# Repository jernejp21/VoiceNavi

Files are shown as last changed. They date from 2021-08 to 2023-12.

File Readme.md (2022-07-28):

# VoiceNavi
For operation manuals, refer to [VoiceNavi](http://www.voicenavi.co.jp/).

## Supported devices

- 5A2
- 5F2
- 5F1
- 5F9IH

To switch between different devices, use MS1<sup>*1</sup> and MS2<sup>*1</sup> solder pads.

MS2 | MS1 | Device
:---: | :---: | :---:
Open | Open | 5A2
Open | Closed | 5F2
Closed | Open | 5F1
Closed | Closed | 5F9IH

## Volume adjustment

If SW2 is put into position 1, 1st song in flash will continuously play and VR3 volume can be adjusted. If position 3 is selected, 1st song in flash will continuously play and VR4 volume can be adjusted. This can be used to adjust volume. Normal operation mode is position 2.

## How to use (on Windows)
To edit source code, use [E2 Studio](https://www.renesas.com/us/en/software-tool/e-studio). Version used for this project is 2021-04 (22.1.0).

**IMPORTANT! Use GCC compiler version 8.3.0.202004. Do not use 8.3.202102 or newer. Compiling doesn't work in 202102 version.**

For updating FW, use [Renesas Flash Programmer V3](https://www.renesas.com/us/en/software-tool/renesas-flash-programmer-programming-gui#download).
 - Power off the device and set **boot** jumper.
 - Move SBPOW1 switch from **Host** to **Slave**.
 - Plug in USB cable and connect to PC.
 - Power on the device. To check if the device is recognised by PC, go to Device Manager and look at Ports.

 device manager
 - In Renesas Flash Programmer, create new project.

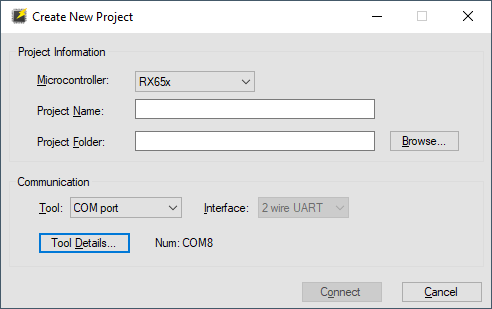
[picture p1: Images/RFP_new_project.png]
new project
 

 - Under *Tool* select *Com port*, under *Tool Details* select port which corresponds to RX USB Boot (Device Manager).
 - Click connect to check if you can connect to device. ID Code is all **F**s.
 - In operation tab, make sure you have **little endian** selected.
 - *Program File* is VoiceNavi.mot, located in VoiceNavi/HardwareDebug. If file or folder is missing, compile the project from E2 Studio or download the file from releases page.
 - Press *Start* button to begin download.
 - After download is completed, turn off power, unplug USB cable, move SBPOW1 back to **Host** and remove **boot** jumper.

## Copy from USB drive to internal flash procedure
To copy data from USB drive to flash, next procedure must be done. Before inserting USB drive, make sure it is formatted to FAT (FAT16, FAT32, exFAT) format and all needed wav files and only one wpj file is on USB drive. If this is not true, error will occur during copy procedure.

**Copy procedure:**
- Turn off power.
- Insert USB flash drive.
- Turn on power.
- During copy process, USB LED (green LED) will be turned on.
- If copying was successful, USB LED will blink in 0,5 s intervals. If errors occur, see error table.
- Turn off power.
- Remove USB flash drive.
- Turn on power.

## Errors table
If error occurs during any time when using VoiceNavi, check error table for details what the cause may be.

**LED colours and names:**
- ALARM - red (LED4)
- POWER - amber (LED1)
- BUSY - yellow (LED2)
- USB - green (LED3)

<table>
<thead>
  <tr>
    <th colspan="2">LED status</th>
    <th>Error type</th>
    <th>Possible cause</th>
  </tr>
</thead>
<tbody>
  <tr>
    <td>USB LED</td>
    <td>ALARM LED</td>
    <td></td>
    <td></td>
  </tr>
  <tr>
    <td>ON</td>
    <td>ON</td>
    <td>File system error</td>
    <td>Flash overflow.</td>
  </tr>
  <tr>
    <td>ON</td>
    <td>blinking (500 ms)</td>
    <td>Wave file error</td>
    <td>WAV file is missing.<br>WPJ file is missing.<br>WAV file is in stereo.<br>USB is formatted in wrong file system. Use FAT file system.</td>
  </tr>
  <tr>
    <td>OFF</td>
    <td>blinking (100 ms)</td>
    <td>Flash ECC error</td>
    <td>Bit error was detected and not corrected. Possibly deteriorated flash.</td>
  </tr>
  <tr>
    <td>OFF</td>
    <td>blinking (500 ms)</td>
    <td>Empty flash error</td>
    <td>No data in flash. Copy data from USB to internal flash.</td>
  </tr>
</tbody>
</table>

## Notes
Above described procedures apply to normal operation mode. If JP1 jumper is soldered, device is in debug mode. Device mode allows user to switch between board types using DIP switch.

*1 - In debug mode use DIP switch 7 and 8. MS1 is 7, MS2 is 8

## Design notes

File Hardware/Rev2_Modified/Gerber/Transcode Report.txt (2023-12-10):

   ---- Transcoding 'C:\Users\ALJAZT~1\AppData\Local\Temp\PCB2_importZIP\PCB2-NonPlated.TXT' ----   Mon May 02 20:12:58 2022

T9   --> T10
-----------------------------------------------------------------

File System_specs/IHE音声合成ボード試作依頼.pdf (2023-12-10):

有限会社 ハイツーシステム様
IHE 音声合成ボード開発依頼

2021 年 4 月 12 日

I.H.E. 井口
1 | 概要
| IHE では三共電子株式会社（以降三共とする）製音声再生ボード WAV-5F9-IH を販売しているが、
| 業務用 CF カード（低容量）の入手が困難になりつつある。
| そのため CF カードを廃止した、WAV-5F9-IH と搭載互換性がある、音声再生ボードの開発を行
| っていただく。
2 | 三共音声再生ボード WAV-5F9-IH 仕様

別紙 納入仕様書「WAVE ファイル再生ボード WAV5F9-IH00」（納入仕様書 WAV5F9-IH00.pdf） を参照して下さい。

3 | 開発音声再生ボード仕様
3.1 | WAV-5F9-IH と完全互換内容
- 基板外形寸法および基板取付穴
- 使用部品（相当品可）および部品配置

端子台：TB1／TB2
モードスイッチ：SW1

LED：LED1(POWER)／LED2(PLAY) ボリューム：VR3／VR4
- 機能および仕様
定格電圧、使用環境、再生方式、再生帯域、
モードスイッチ（プログラムローダ機能は別途相談）、
制御モードおよび CH 数、制御タイミング、
スピーカ出力、音量調整 VR3/VR4、

端子台 TB1/TB2 ピンアサイン、POWER-LED、PLAY-LED
3.2 三共音声再生ボードからの変更点
- 音声データおよび管理データが保存されている CF カードを廃止し、代わりにフラッシュメ モリ（128MB 以上）を搭載して下さい。
- マイコンおよびマイコン周辺回路の選定は一任します。
- オーディオ用 D/A コンバータの選定は一任します。
- D 級アンプと前段フィルタは、別紙 回路図「IH001V2 Rev:D1」（IHE001(D1).pdf） を参考にして下さい。
3.3 音声データと管理データ
- 三共製 VoiceNavi Editor で生成された音声ファイル（WAV ファイル）と管理ファイル（WPJ ファイル）を使用します。それらファイルを音声再生ボードに実装したフラッシュメモリに 転送し、制御入力に対した音声再生を行ないます。VoiceNavi Editor に相当するアプリケー

ションの開発は不要です。

- 転送方法は、別紙 三共 WAV-5M2F の方法（Lieflet_WAV5M2F.pdf）が望ましいですが、最 低機能として以下が実装できれば問題ありません。
- パソコン内にある三共製 VoiceNavi Editor で生成された音声ファイルと管理フ ァイルを、パソコン上で USB メモリあるいは SD カードにコピーする。
- USB メモリあるいは SD カードを音声再生ボードに装填し、音声再生ボードを 起動すると、音声ファイルと管理ファイルが音声再生ボード上のフラッシュメモ リにコピーされる。
- 音声再生ボードに USB メモリあるいは SD カードが装填されていなければ、フ ラッシュメモリから制御入力に対した音声再生を行う。
3.4 管理ファイル（WPJ ファイル）について
- 別紙に管理ファイル（4_01917A.wpj）テキスト形式を参照して下さい。必要な情報 はファイル内の#2 と#3 です。
- #2 では、ファイル番号に音声ファイル名を定義しています。音声ファイル名と拡張 子は、8 文字以下.3 文字以下です。

#2

0,NR053A.wav | ファイル番号 0 に NR053A.wav ファイルを紐づけ
1,NR047.wav | ファイル番号 1 に NR047.wav ファイルを紐づけ
2,056A.wav | ファイル番号 2 に 056A.wav ファイルを紐づけ
：

58,BB001.wav ファイル番号 58 に BB001.wav ファイルを紐づけ

- #3 では、制御入力 CH に対する、出力系統（1=VR3、2=VR4）、リピート回数、音声 ファイル組立を定義しています。
カンマ区切りで構成され、
1 番目は制御入力 CH（0=0x01、1=0x02…254=0xFF） 2 番目は出力系統（1=VR3 経由出力、2=VR4 経由出力） 3 番目はリピート回数
4 番目以降は音声ファイル組立（最大 8 ファイル）

#3

0,1,1,58 | 入力 0 は VR3 系統/リピート 1 回/ファイル番号 58 を再生
1,1,1,45 | 入力 1 は VR3 系統/リピート 1 回/ファイル番号 45 を再生
：
6,2,1,6 入力 6 は VR4 系統/リピート 1 回/ファイル番号 6 を再生
：

13,1,1,13,14 入力 13 は VR3 系統/リピート 1 回/ファイル番号 13,14 を組立再生

14,1,1,15,14 入力 14 は VR3 系統/リピート 1 回/ファイル番号 15,14 を組立再生

1 番目の後にカンマ区切りなしで * の場合は、その制御入力 CH は割り当てがないこ

とを意味し、再生は行われません。
8* | 入力 8 は音声再生なし

以上

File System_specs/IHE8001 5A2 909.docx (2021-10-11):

次期音声再生システムソフトウェア設計概要

2021/10/4 V0.3

有限会社ハイツーシステム

改訂履歴

Ver | 日付 | 概要 | 担当
０．２ | 2021/9/3 | 初期 | 池田
０．３ | 2021/10/4 | 一部変更 | 池田

# 1． 概要

次期音声再生システム（音声再生ボード）のソフトウェア概要について説明する。

本システムのおもな機能は以下の通りとする。

・再生用の音声データはPC上で作成された １つのコントロールファイル(.wpjファイル)＋WAVファイル(複数)のファイル群とする。

・これらのファイルを、USBフラッシュメモリにコピーし、USBフラッシュメモリから再生用ボードにコピーする。

・音声再生は、接点入力制御信号を起点として、格納された音声データを再生する。

・再生ボード上のPIOから入力さる接点制御信号はbit単位、またはバイナリコードとして解釈された番号を再生データのチャンネルデータとして、再生する。

・音声の再生モード機能は、旧WAV-5FIH、WAV-5F1、WAV-5F2ボードおよびWAV5A2の各機種と互換の再生モード機能を、合わせて搭載する。

# 2． 参照資料

参考資料として、以下のドキュメントを合わせて参照のこと。

ドキュメント名称 | 内容説明 | 発行者等メモ
IHE音声合成ボード試作依頼.pdf | 作成依頼仕様の概要 | IHE
納入仕様書WAV5F9-IH00.pdf | 前WAV-5F9IH再生ボード仕様書 | S社
65CIH02仕様書_IUK.PDF | 旧IH仕様音声再生ボード仕様
PS_WAV5F1_A130829.pdf | 製品仕様書 音声再生ボード WAV-5F1
PS_WAV5F2_C120416.pdf | 製品仕様書 音声再生ボード WAV-5F2
UM_WAV5F1_A130829.pdf | 取扱説明書4CH接点制御タイプ 音声再生ボード WAV-5F1
UM_WAV5F2_5F2R.pdf | 取扱説明書 音声再生ボード WAV-5F2
4_01917A.wpj | wpjサンプルファイル（テキスト）
音声再生ボード再生モード一覧.xlsx | 音声再生モード機能の資料 | Hi2

# 3． 設定機能について

本システムは、再生機能を実行する前に、ソフトウェアの基本機能を選択設定しておく必要がある。

それら選択項目について下記の基板レイアウト（暫定版）の位置をもとに説明をする。

図中の①~⑳番号で示す。

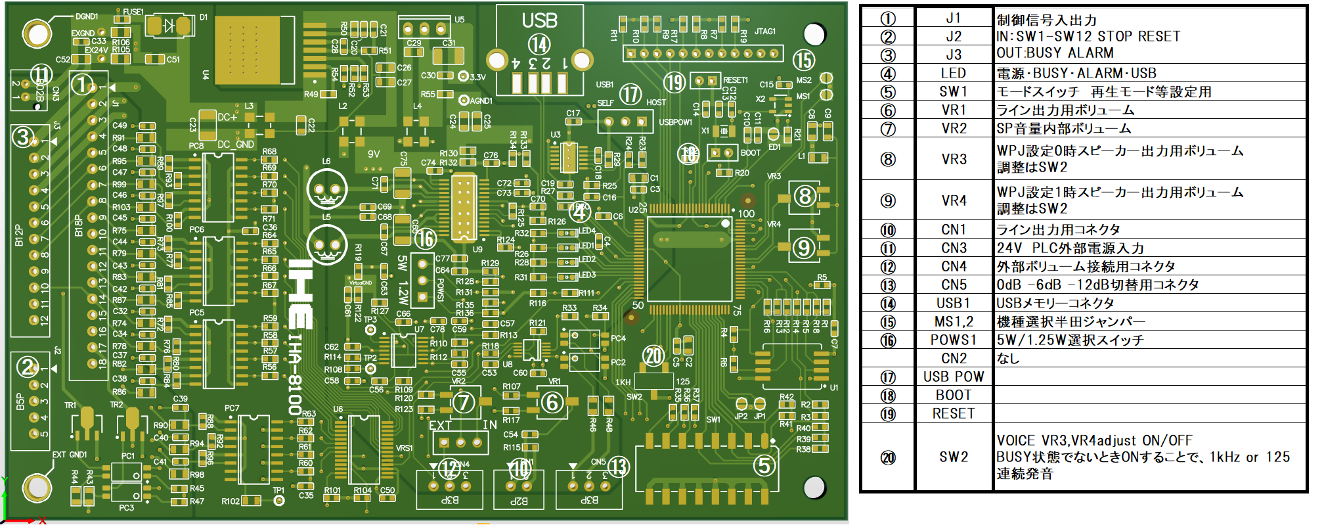
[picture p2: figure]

基板レイアウト暫定版

## 1） 機種の選択 ⑮

本システム（ボードおよびソフトウェア）は、4機種分の機能を内蔵している。これら4機種のどの機種で起動するかを、ボード上の半田ショート（PIO入力）により選択する。

選択する機種は次の 4機種である。

・WAV-5A2

・WAV-5F2

・WAV-5F1

・WAV-5F9

半田ショートパッドは2個あり、このパッドをショートすることにより選択する。

半田パッドNO | １ | ２
WAV-5A2 | オープン | オープン
WAV-5F2 | ショート | オープン
WAV-5F1 | オープン | ショート
WAV-5F9IH | ショート | ショート

## 2） 再生機能モード、その他の機能用 DIP-SW ⑤

再生モードなどソフトウェア機能の選択するために、DIP-SWが用意される。DIP-SWは８点のSWで、以下のように各機能を設定する。

DIP-SW機能設定

１ | ２ | ３ | 4 | 5 | ６ | ７ | ８
再生モードの設定 | | | インターバルタイマ設定 | | 未使用（予備）

a) 音声再生モードの設定

音声再生モードは DIP-SW 1-3 の以下の組合せによる。（５A2モードの場合）

１ | ２ | | | ３ | 再生モード
| | | | | 接点制御-通常再生（WAV-5F9の場合は専用再生）
ON | | | | | 接点制御－後入力切替え再生モード
| ON | | | | 接点制御－優先順位再生モード
ON | ON | | | | 接点制御－入力中再生モード
| | | | ON | バイナリ制御A-6650V2/VF2互換モード120CH(負論理)
ON | | | | ON | 予備
| ON | | | ON | バイナリ制御1(正論理) 250CH
ON | | ON | ON | | バイナリ制御2(負論理) 250CH

音声再生モードは DIP-SW 1-3 の以下の組合せによる。（５F2モードの場合）

１ | ２ | | | ３ | 再生モード
| | | | | 接点制御-通常再生（WAV-5F9の場合は専用再生）
ON | | | | | 接点制御－後入力切替え再生モード
| ON | | | | 接点制御－優先順位再生モード
ON | ON | | | | 接点制御－入力中再生モード
| | | | ON | 予備
ON | | | | ON | バイナリ制御A-6650V2/VF2互換モード127CH
| ON | | | ON | バイナリ制御1(正論理) 255CH
ON | | ON | ON | | バイナリ制御2(負論理) 255CH

音声再生モードは DIP-SW 1-3 の以下の組合せによる。（５F1モードの場合）

１ | ２ | | | ３ | 再生モード
| | | | | 接点制御-通常再生（WAV-5F9の場合は専用再生）
ON | | | | | 接点制御－後入力切替え再生モード
| ON | | | | 接点制御－優先順位再生モード
ON | ON | | | | 接点制御－入力中再生モード
| | | | ON | 予備
ON | | | | ON | 予備
| ON | | | ON | 予備
ON | | ON | ON | | 予備

音声再生モードは DIP-SW 1-3 の以下の組合せによる。（５F9IHモードの場合）

１ | ２ | | | ３ | 再生モード
| | | | | 専用接点制御
ON | | | | | 専用バイナリ制御(負論理) 255CH
| ON | | | | 予備
ON | ON | | | | 予備
| | | | ON | 予備
ON | | | | ON | 予備
| ON | | | ON | 予備
ON | | ON | ON | | 予備

b) 各種再生モードの説明

再生モード | 対象機種 | 再生モードの概略説明
接点制御-通常再生 | WAV-5A2 WAV-5F2 WAV-5F1 | ワンショット／レベル入力 パルス幅50msec以上 ワンショット1回、レベルーリピート再生 再生終了後、他SW入力を検知します。 複数のレベル入力の場合、交互に再生します。 (再生中は他のSW入力を検知しない)
| WAV-5F9 | 入力 12bit ワンショット入力 パルス幅15msec以上 ワンショット1回、レベル1回 リピート再生しない 再生中他のSW入力を検知、入力があると入力CHを再生。 標準の後入力切替再生と類似
接点制御－後入力切替え 再生モード | WAV-5A2 WAV-5F2 WAV-5F1 | ワンショット入力のみ、※レベル入力－不可 パルス幅50msec以上 再生終了後、他SW入力を検知します。 再生中は、当該ＳＷを含む全てのＳＷを検出し、入力されると即座に入力されたＳＷのメッセージに切り替わります。接点がレベル入力された状態でも登録されている音声を1 回再生して終了し、再生待機状態となります。
接点制御－優先順位再生モード | WAV-5A2 WAV-5F2 WAV-5F1 | レベル入力※ワンショット入力－優先順位に注意 [優先順位] SW1>SW2>・・・・>SW7>SW8 再生中、優先順位の高いSW入力を検知した場合、強制終了。該当するSWの音声データを再生。
接点制御－入力中再生モード | WAV-5A2 WAV-5F2 WAV-5F1 | レベル入力※ワンショット入力－不可 入力中のみ、再生します。入力終了と同時に再生を終了します。 (再生中は他のSW入力を検知しない) (使用用途)発車・開演ブザー・サイレン音の演奏
バイナリ制御-6650V2/VF2互換モード128CH | WAV-5A2 WAV-5F2 | D0-6でアドレス設定、STBで再生、MAX126CH FFH(7FH)-再生強制終了 音声20ch分バッファリング機能あり
バイナリ制御(正論理) 255CH | WAV-5F2 | D0-7でアドレス設定、STBで再生、MAX255CH 00H-再生強制終了 （5A2はFFHで停止） 音声20ch分バッファリング機能あり
| WAV-5A2 | MAX250CHまで
バイナリ制御2(負論理) 255CH | WAV-5F2 | D0-7でアドレス設定、STBで再生 1CH=FEH、2CH=FDH 、FFH-再生強制終了 MAX 255CH 音声20ch分バッファリング機能
| WAV-5A2 | D0-7でアドレス設定、STBで再生 1CH=FAH、2CH=F9H……、MAX250CH 音声20ch分バッファリング機能
| WAV-5F9 | D0-7でアドレス設定、STBで再生 1CH=FEH、2CH=FDH 、FFH-再生強制終了 MAX 255CH 音声20ch分バッファリング機能 STB信号は立下りで検知する。

※各機種のDIP－SW設定と再生モードの詳細動作については、各機種ごとの取り扱い説明書を参照のこと。

また、「音声再生ボード再生モード一覧.xlsx」をも合わせて参照

c) インターバルタイマの設定

インターバルタイマは、接点制御、通常再生モードで有効です。

４ | ５ | インターバルタイマ機能
| | インターバルタイマ0秒
ON | | インターバルタイマ30秒
| ON | インターバルタイマ60秒
ON | ON | インターバルタイマ120秒

## 3） テスト用SW ⑳

内蔵テストプログラムの起動　※TBD

## 4） Reset ジャンパピン ⑲

ハードウェアリセットを実行する。

## 5） Bootジャン ⑱

プログラム書込み時にON状態として、書き込みモードとなる。

## 6） USB電源選択ジャンパ ⑰

機能のホスト/デバイスを選択する際に、電源供給を切り換える。

通常はHOST側、プログラム書き換えの際には、SLAVE側を選択する。

# 4． 音声再生音源データファイル

音声再生で、再生対象となるのはWAVファイルであるが、複数のWAVファイルを再生チャンネルごとにまとめ、制御するための再生制御用ファイル（ .WPJファイル）を必要とする。

これらのファイルは、PCで作成されたのち、USBフラッシュメモリから再生ボードに搭載されたフラッシュメモリにコピーする

## 1） 音声再生音源データのコピー方法

音声再生の音源データ（再生用データ）は、ボード上フラッシュメモリに格納されていることを前提とする。

PCで作成した再生用データをコピーするには、以下の手順で行う。

a) 音声データの入ったUSBフラッシュメモリをUSBポートに挿入してから、ボードの電源を入れる。USBLEDが点灯する、
b) この際に、ボード上フラッシュメモリに既にデータが入っている如何に関わらず、メモリをクリアし、USBフラッシュメモリ上のデータをシリアルフラッシュにコピーする。
c) コピー後、ボード上のUSBLEDがスロー点滅となり。この状態USBメモリを取り外し可能となり、USBメモリ取り外し後、電源を入れなおす。　その後通常の音声再生状態になる。

## 2） 再生制御用ファイル ｗｐｊファイルのフォーマット

ｗｐｊファイルは、テキストファイルで以下の形式で情報を格納する。

※ｗｐｊファイルについては、IHEの「IHE音声合成ボード試作依頼.pdf」の3.4 管理ファイル（ WPJ ファイル）にも説明が記載されている。

行先頭が、”#n”（ｎは数値）である行以降の行が意味のある情報で、次の”#n’”まで、またはファイル終了までがｎセクションの有効情報とする。（ｎ数の順番は問わない）

“#0”セクション

作成者などの情報、再生機能上は使用しない

“#1”セクション

メモリの容量、名称などの情報、再生機能上は使用しない

“#2”セクション

WAVファイルを、IDNo.で登録するためのセクション、

1行に、“音声登録No., Wavファイル名”の形式で、音声登録NO,とWAVファイル名称の対応付けを示す。

“#3”セクション

再生用音声Ch登録情報のセクション

再生指定Chがどの音声ファイルを再生するかを登録した情報、1行単位で、フォーマットは以下

“登録ChNo., 出力系統（VRNo.）, リピート回数, 登録WavファイルNo.（複数可）”

1行中に音声ファイルは複数可能で、その際には、ｃｈ信号に対して、複数の登録WAVファイルを連続して再生する

1番目の後にカンマ区切りなしで* の場合は、その制御入力CHは割り当てがないことを意味し、再生は行われません。

(例) 8* //入力8CHは音声再生なし

# 5． 音声再生のシーケンス概要

通常、電源投入後から、以下の手順で音声再生が実行される。

（５章の「ソフトウェア処理フロー」も参照）

## a) 起動時には、DIP-SWをチェックし、音声の再生のモードを決定する。

その後、音声再生信号待ち状態となる。接点制御の場合は、PIO8bit分(4bit/12bit)を監視、バイナリ制御の場合は、STB信号を監視する。

## b) 再生信号の入力時

音声再生モードが、接点制御の場合、接点信号の入ったbitに該当する、Ch no.の音声を再生する。

バイナリ制御の場合は、STB信号入力時 PIO8bit分をバイナリコードとした値をCh no.

として、再生する。

## c) 音声の再生

音声再生は、ｗｐｊファイルの#3セクション 再生Ch. 情報に基づき再生する。

#3セクションの VR選択情報、登録されたWavファイル情報（複数）により再生を実行する。

再生は、Wavファイルのヘッダに記載されたサンプリング周波数で、CPU内蔵のDACから出力することにより実行する。

#3セクションのリピートフラグがONの場合、指定回数分、Wavファイル再生を繰り返す。（WAV５F9では不要？）

・再生中は、再生LED転倒、BUSY信号出力

・再生中は、STOP信号を監視し、STOPONの時、再生を停止する。

## d) 再生終了後

再生終了後は再度、音声制御信号入力待ちとなり、音声再生信号の監視状態にもどる。

# 6． WAV5F9の音声再生について

WAV5F9は特注機種であり、他の3機種と機能的に異なる。

もともと、古い機種である65CIH02の機能をベースとしている。再生モードは以下の2種のみである。

a. 接点制御モード　12bit信号のどれか1bitONで再生する。音声プログラムChは12

入力信号は IN1~IN12 「納入仕様書 WAV5F9-IH00.pdf」のP７、専用接点制御モード (65CIH02 互換)の場合のピンアサイン参照

b. 専用バイナリ制御モード（負論理） 8bit信号データをバイナリーコードとして認識し、

音声プログラムCh 256種類を再生する。信号データ取り込タイミングは、STB信号による。

入力信号は D0~D7 「納入仕様書 WAV5F9-IH00.pdf」のP７、専用バイナリ制御モードの場合のピンアサイン参照、また信号取り込タイミングは、P5の「タイミングチャート」参照

# 7． 再生ボード機能ブロック

CPU

Renesas

RX651

NANDFlash ROM

128MB

USB

フラッシュ

USB

デバイス

IF

・USB Drv

ホスト→

デバイス

変換ケーブル

将来

・FAT Drvアクセス

WAV再生ボード

内蔵DAC

・PIO入力(再生用制御信号)

12bit接点 or

8bit binaryデコード、STB、BUSY

アンプ回路

(VRのみ2系統搭載)

PCからプログラム書き換え

PIO

QSPI

・FAT Drv

USB

ホスト

IF

機能ブロック図

1） ハードウェア詳細は、次期音声再生ボード 回路図、部品表を参照のこと。

※この項 後で追記 TBD

2） ~~USBドライバ、~~~~FAT~~~~ファイルシステムは、Renesasミドルウェア~~~~利用を前提とする。~~

~~USBについて、当面必要なのはUSBフラッシュメモリの読込ホスト機能のみだが、将来的な拡張性から~~~~PCと接続してストレージとなるデバイス機能も必要~~

~~（~~~~OTG機能~~~~、ジャンパで~~~~切り替え~~~~が~~~~可能~~~~とする）~~

3） ~~音声再生制御の入力信号は、~~~~選択される~~~~機種により~~~~Portが異なる。ソフトウェアで~~~~機種ごとに~~~~切り替える。（機種選択機能は、半田パッドによる）~~

# 8． ソフトウェア処理フロー

起動

ハード初期化

システム初期処理

・機種選択読込、機種設定

・DIP-SW読込

機種＋DIP-SWで再生モード設定

音声制御信号待ち

音声再生初期化処理

・再生Chデータ準備

・音量VR選択

・音声データバッファリング

・タイマセット他

音声再生スタート

・周期音声再生出力処理

・音声データバッファリング

音声ファイル終了

STOP信号？

組立複数ファイル登録？

Y

Y

Y

信号入力

N

N

N

音声再生システム概略フロー

リピート？

Y

N

音声データ読込準備

・wpjファイル読込、チェック

音声ファイル情報設定

USBフラッシュ挿入あり

USBフラッシュ→ボードフラッシュ 音声データコピー処理

USBフラッシュ抜去？

・終了処理

・ディレイタイマセット待ち

Y

# 9． ボード上、ＮＡＮＤフラッシュメモリ内フォーマット

ＵＳＢフラッシュより読み込んだ、ｗｐｊファイルデータ、ＷＡＶファイル音源データは、ＮＡＮＤフラッシュメモリにバイナリフォーマットに格納される。

フラッシュ・ページ 3: flash_table[255] (音楽のアドレス)

フラッシュ・ページ 5: output_music[255] (整理したwpjファイル)

フラッシュ・ページ 8以降: すべてのwavファイル（バイナリ）

# 10． 将来拡張性について

・プログラム書き換えは、USBポートからＰＣによる書込みで対応、USBポートは通常ホスト機能であるが、書換時にはデバイスとして動作（変換ケーブルを準備）

・将来的にUSBフラッシュメモリからのプログラムローダー機能追加の見込みあり、拡張性を考慮する。

・PC上のGUIベース音声データ作成、編集アプリは当面不要とする。

・MP3再生は当面不要とする。

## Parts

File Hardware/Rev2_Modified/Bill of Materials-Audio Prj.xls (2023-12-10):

Designator | Quantity | Description | Comment | Pins | Library Reference
BOOT, RESET1 | 2 | 雄,ストレート,1列2ピン | HEDDER2 2mm | 2 | HEDDER2 2mm
C1, C2, C8, C9, C55, C58, C70, C72, C73, C76 | 10 | セラコン1608サイズ | TMK107BJ105MA-T | 2 | C1608
C3, C4, C5, C6, C10, C11, C15, C16, C17, C18, C19, C30, C32, C33, C34, C35, C36, C37, C38, C39, C40, C41, C42, C43, C44, C45, C46, C47, C48, C49, C50, C53, C61, C64, C68, C69, C77, C78 | 38 | セラコン1608サイズ | CGA3E2X7R1H104K080AA | 2 | C1608
C7, C20, C21, C28 | 4 | セラコン1608サイズ | GCD188R71H103KA01D | 2 | C1608
C12, C13 | 2 | セラコン1608サイズ | GCM1885C2A150FA16D | 2 | C1608
C14, C60, C62, C74 | 4 | セラコン1608サイズ | GCM1885C2A102JA16D | 2 | C1608
C22, C29, C51, C52 | 4 | セラコン2012サイズ | GRM21BR71H474MA88 | 2 | C2012
C23 | 1 | セラコン3225サイズ | UMK325C7106MM-T | 2 | C3225
C24, C25, C26, C27 | 4 | セラコン2012サイズ | TMK212BBJ106MG-T | 2 | C2012
C31 | 1 | セラコン3225サイズ | EMK325ABJ107MM-T | 2 | C3225
C56 | 1 | セラコン1608サイズ | GCM1885C2A471JA16D | 2 | C1608
C57 | 1 | セラコン1608サイズ | GCM1885C2A221JA16D | 2 | C1608
C59 | 1 | セラコン1608サイズ | GCM1885C2A682JA16D | 2 | C1608
C63, C75 | 2 | 6.3φ 電解コンデンサ | UCQ1C101MCL1GS | 2 | 6.6 X 6.6
C65, C71 | 2 | セラコン1608サイズ | UMK107B7474KA-TR | 2 | C1608
C66, C67 | 2 | セラコン2012サイズ | TMK212BJ105KG-T | 2 | C2012
CN1, CN3 | 2 | 雄,ストレート,1列2ピン | B2P-SHF-1AA | 2 | B2P-SHF-1AA
CN4, CN5 | 2 | 雄,ストレート,1列3ピン | B3P-SHF-1AA | 3 | B3P-SHF-1AA
D1 | 1 | Schottky Rectifier | SIPS3150U | 2 | Diode SMB 5.4x4.3
D2 | 1 | DIODE SCHOTTKY 30V 800MA USC | CUS08F30 | 2 | CUS08F30
FUSE1 | 1 | 3A 1608サイズ | ERB-RE3R00V | 2 | TF1608
J1 | 1 | 雄,ストレート,1列12ピン PCB | B18P-SHF-1AA | 18 | B18P-SHF-1AA
J2 | 1 | 雄,ストレート,1列3ピン | B5P-SHF-1AA | 5 | B5P-SHF-1AA
J3 | 1 | 雄,ストレート,1列12ピン PCB | B12P-SHF-1AA | 12 | B12P-SHF-1AA
JTAG1 | 1 | HEDDER12 2mm | HEDDER12 2mm | 12 | HEDDER12 2mm
L1 | 1 | SMD Inductor 2012size | MLZ2012N101LT000 | 2 | MLZ2012
L2, L4 | 2 | コモンモード,1A,4ピン | DLW5BTM142TQ2L | 4 | ACM3225
L3 | 1 | コモンモード,1A,4ピン | DLW5BTM142TQ2 | 4 | ACM3225
L5, L6 | 2 | Shielded Inductor | NR6028T330M 33uH | 2 | DR125
LED1, LED5 | 2 | LED 1608 orange | APT1608LSECK/J4-PRV | 2 | LTST-C190CKT
LED2 | 1 | LED 1608 yellow | APT1608LSYCK/J3-PRV | 2 | LTST-C190CKT
LED3 | 1 | LED 1608 green | APT1608LZGCK | 2 | LTST-C190CKT
LED4 | 1 | LED 1608 RED | APT1608LSECK/J3-PRV | 2 | LTST-C190CKT
OPT1, OPT2 | 2 | 60V 550mA フォトモス | AQY212G2SX | 4 | AQY225R2S
PC1, PC2, PC3, PC4 | 4 | PHOTOCOUPLER 1ch | TLP291(SE | 4 | TLP291
PC5, PC6, PC7, PC8 | 4 | 4 Channel 16-SO | PS2801-4-F3-A | 16 | TLP621
POWS1, USBPOW1, VRS1 | 3 | SPDTスライドスイッチ | SS12D01G4 | 3 | SS12D01G4
R1, R5, R6, R7, R8, R9, R10, R11, R17, R19, R111, R115, R135, R136 | 14 | 厚膜チップ抵抗1608サイズ | ERJ-PA3F4701V | 2 | TF1608
R13, R15, R27, R30, R128, R130 | 6 | 厚膜チップ抵抗1608サイズ | ERJ-PA3F22R0V | 2 | TF1608
R20, R22, R23, R24, R25, R56, R57, R58, R59, R60, R61, R62, R63, R64, R65, R66, R67, R68, R69, R70, R71, R72, R73, R76, R77, R80, R81, R84, R85, R88, R89, R92, R93, R96, R97, R100, R101, R104, R107, R116, R121, R122, R123, R127, R133, R138 | 46 | 厚膜チップ抵抗1608サイズ | ERJ-PA3F1002V | 2 | TF1608
R21, R29, R33, R34, R35, R36, R37, R38, R39, R40, R41, R42, R49, R108, R125, R140 | 16 | 厚膜チップ抵抗1608サイズ | ERJ-PA3F1003V | 2 | TF1608
R26, R28, R31, R32, R117 | 5 | 厚膜チップ抵抗1608サイズ | ERJ-PA3F2001V | 2 | TF1608
R43, R44 | 2 | 薄膜チップ抵抗2012サイズ | RK73B2ATTD472J | 2 | MF2012
R45, R47, R52, R53, R54 | 5 | 厚膜チップ抵抗1608サイズ | ERJ-PA3F1001V | 2 | TF1608
R46, R48, R74, R75, R78, R79, R82, R83, R86, R87, R90, R91, R94, R95, R98, R99, R102, R103 | 18 | 薄膜チップ抵抗2012サイズ | RK73B2ATTD392J | 2 | MF2012
R50 | 1 | 厚膜チップ抵抗1608サイズ | ERJ-PA3F3602V | 2 | TF1608
R51 | 1 | 厚膜チップ抵抗1608サイズ | ERJ-PA3F3301V | 2 | TF1608
R55, R105, R106, R119, R120, R134 | 6 | 厚膜チップ抵抗1608サイズ | RK73Z1JTTD | 2 | TF1608
R109, R110, R126, R131, R132 | 5 | 厚膜チップ抵抗1608サイズ | ERJ-PA3F3601V | 2 | TF1608
R112 | 1 | 薄膜チップ抵抗2012サイズ | RK73B2ATTD911J | 2 | MF2012
R113 | 1 | 厚膜チップ抵抗1608サイズ | ERJ-PA3F1201V | 2 | TF1608
R114 | 1 | 厚膜チップ抵抗1608サイズ | ERJ-PA3F1302V | 2 | TF1608
R118 | 1 | 厚膜チップ抵抗1608サイズ | ERJ-PA3F5100V | 2 | TF1608
R124 | 1 | 厚膜チップ抵抗1608サイズ | ERJ-PA3F3902V | 2 | TF1608
R129 | 1 | 厚膜チップ抵抗1608サイズ | ERJ-PA3F2002V | 2 | TF1608
R137, R139 | 2 | 厚膜チップ抵抗1608サイズ | RR0816P-271-D | 2 | TF1608
SW1 | 1 | SMD DIP Switch | 219-8MST | 16 | 219-8MST
SW2 | 1 | SWITCH SLIDE SPDT 100MA 6V | CJS-1201TB | 3 | CJS-1201TB
TR1, TR2 | 2 | NPN TR 1A with Resi | DTDG14GPT100 | 3 | DTC114YKAT146_1
TR3 | 1 | NPN TR 0.1A SC85 2x2.1 SOC323 | DTC114YUBHZGTL | 3 | DTC114YUBHZGTL
U1 | 1 | IC FLASH 4GBIT SPI/QUAD I/O 8LGA | AS5F34G04SND-08LIN | 8 | AS5F34G04SND-08LIN
U2 | 1 | MCU | R5F5651EHDFP#30 | 100 | RX62NxxDFP 100pin
U3 | 1 | IC REG CHARG PUMP ADJ/PRG 12MSOP | LTC3245EMSE#PBF | 12 | LTC3245EMSE#PBF
U4 | 1 | DC DC CONVERTER 5-30V | LMZ14202HTZ/NOPB | 8 | LMZ14202HTZ/NOPB
U5 | 1 | DC DC CONVERTER 3.3V | TPSM84203EAB | 3 | TPSM84203EAB
U6 | 1 | I/O Expander 16 SPI 10MHz 28-SOIC | MCP23017-E/ML | 28 | MCP23017-E/ML
U7 | 1 | IC OPAMP JFET 4 CIRCUIT 14TSSOP | TL074CPWR | 14 | TL084CPT
U8 | 1 | IC DGTL POT 10KOHM 128TAP 10UMAX | DS3502U+T&R | 10 | DS3502U+T&R
U9 | 1 | IC AMP CLASS D STER 10W 28HTSSOP | TPA3140D2PWPR | 28 | TPA3140D2PWPR
USB1 | 1 | CONN RCPT USB2.0 TYPEA 4P SMD RA | 87583-3010RPALF | 4 | 87583-3010RPALF
VR1 | 1 | CERMET TRIMMER Top adjustmet | ST4ETB202 | 3 | ST-32EA**
VR2, VR3, VR4 | 3 | CERMET TRIMMER Top adjustmet | ST4ETB503 | 3 | ST-32EA**
X2 | 1 | OSC MEMS ＳＯＴ－２３－５ | SIT2001BI-S2-33E-12.000000 | 5 | SIT2001BI-S2-33E-xxx

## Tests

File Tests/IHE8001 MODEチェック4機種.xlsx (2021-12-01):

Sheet: MODE
基本MODE DIP SW | 実質 MODE | 機種 MODE | 5A2 入力BIT数=8 1-3: MODE; 45: インターバル; 68: 空 (減音なし); 7: Flash copy | 5F2 入力BIT数=8 1-3: MODE; 45: インターバル; 68: 空; 7: Flash copy | 5F1 入力BIT数=４ 1-3: MODE; 45: インターバル; 68: 空; 7: Flash copy | 65CIH02（5F9基板使用） （5F9仕様は実装不要） 入力BIT数=12 SP出力は打合による8W⇒5Wとする。 MODE 1: 通常再生 2: 専用バイナリ制御
1 000 | 1 | 1 接点 通常再生 | インターバルタイマ無 ①1回再生、再生中他の入力無視 ②再生終了後にSWスキャン | ← | ←
 | 2 |  | インターバルタイマー有 再生終了後タイマー動作 動作中SW無視 STOP有効 | ← | ←
 | 3 | 65CIH02 専用接点制御 |  |  |  | ONSHOT only 立ち下がり15ms（50msでない） 再生途中でも後入力CHに即座に切替 ﾚﾍﾞﾙ入力された場合1回再生し、待ち状態とする。 WPJ内の音量選択あり
2 001 | 4 | 5A2,5F2,5F1 接点 後入力切替再生 | インターバルタイマ無 ONESHOT only 1回再生 再生中SWスキャン (押された全SW順に)即座に変更 STOP有効 | ← | ←
 | 5 | 65CIH02 専用バイナリ制御（負論理） |  |  |  | 負論理 5F2の制御2と同じ。Ch: 255 STOP: FFh or 00h バッファリング20ch 保持 減音なし
3 010 | 6 | 5A2,5F2,5F1 接点 優先順位再生 | インターバルタイマ無 ONESHOT 1回 Levelリピート連続 即座に変更 優先処理 1, 2, 3… | ← | ← | 空
4 011 | 7 | 接点 入力中再生 | インターバルタイマ無 ONESHOT無 SW入力中のみ繰り返し含み再生 SWが切れるとSTOP相当 | ← | ← | 空
5 100 | 8 | 5A2 バイナリ制御3; 126負論理 | バイナリ制御3 6650V2互換 1-126 20ch保持 BUSY L 1 = 7Eh STOP: 7Fh or 00h SW8減音なし | ← | 空 | 空
6 101 | 9 | 5F2 バイナリ制御A | 空 | maybe 5A2 制御3に近い 6650V2互換 D0-D6 20ch 保持 BUSY L 1 = 7Eh STOP: FFh or 00h SW8減音なし | 空 | 空
7 110 | 10 | 5A2 バイナリ制御1; 250負論理 | バイナリ制御１ 1-250 バッファリング20ch保持 BUSY L 1 = FAh STOP: FFh or 00h SW8減音あり 減音大リセットFDh 中FBh 小FChは無し |  | 空 | 空
 | 11 | 5F2 バイナリ制御1 |  | 正論理 5A2の制御2となる。Ch: 254 STOP: 00h or FFh バッファリング20ch保持 減音なし
8 111 | 12 | 5A2 バイナリ制御2; 250正論理 | バイナリ制御２ 1-250 バッファリング20ｃｈ保持 BUSY H 1 = 01h STOP: FFh or 00h SW8減音あり 減音大リセットFDh 中FBh 小FChは無し |  | 空 | 空
 | 13 | 5F2 バイナリ制御2; 254負論理 |  | 負論理 5A2の制御1となる。Ch: 254 STOP: FFh or 00h バッファリング20ch保持 減音なし

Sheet: 共通仕様
 | 項目
No. | ●点灯 ◎点滅 －消灯 | ALM | MCU | BUSY | USB | POW （量産版未確認） | チェック
2 | 電源ON | － | － | － | － | ●
3 | MCU準備完了 | － | ● | － | － | ●
4 | 音声出力中（BUSY出力と同じ） | － | ● | ● | － | ●
5 | USBメモリ接続 | － | ● | － | ● | ●
6 | USBメモリFLASH転送中 | － | ● | － | ● | ●
7 | USBメモリFLASH転送完了 | － | ● | － | ◎点滅 500 ms | ●
8 | USB File system error | ● | ● | ◎点滅 | － | ●
9 | FLASH WAV・WPJ合わない | － | ● | ◎点滅 | － | ●
10 | FLASHにデータなし(起動時) | ◎点滅 | ● | － | － | ●
11 | FLASH ECC error | ● | ● | － | ◎点滅 100 ms | ●
12 | BOOT | － | － | － | － | ●
 |  | ※LED点灯方法を修正 2021/10/6 Hi2
 |  | ※MCUのライフチェックとして、1秒程度の点滅でお願いします。
No. | 項目 | 内容 |  |  |  |  | チェック
1 | 消費電力12V無動作 | 50ｍA(実測値） |  |  |  |  | レ
2 | 消費電力12V最大 | 50mA+580ｍA≒650mA（机上計算） |  |  |  |  | レ
3 | 消費電力24V無動作 | 30ｍA(実測値） |  |  |  |  | レ
4 | 消費電力24V最大 | 30mA+300mA≒350ｍA（机上計算） |  |  |  |  | レ
5 | 音声ファイル | 下記
6 | 44.1ｋHz 16bit 8bit
7 | 22.05kHz 16bit 8bit
8 | 11.025kHz 16bit 8bit
9 | 32kHz 16bit 8bit
10 | 16kHz 16bit 8bit
11 | 8kHz 16bit 8bit
12 | 再生帯域 | ローパスフィルタ設計カットオフ 音声を聞いて判断
13 | 不良音声ファイル | WAVなし、WPJなし、・・・・似て確認 フェイルLEDにて確認
14 | 外形サイズシルク | 130/80 IHE IHA-8001 |  |  |  |  | レ
15 | 外形サイズ5F9シルク | 172/122 IHE IHA80 |  |  |  |  | レ
16 | ウオッチドックタイマ | 初期動作復帰
17 | USBデータ読み込み | 各モードでの確認による |  |  |  |  | レ
18 | ONボードメモリ | USB⇒フラッシュ書込で確認 型名AS5F34G04SND
19 | PC BOOT | Renesas Flash Programmer V3.08.03にてソフトウェア書込で確認 |  |  |  |  | レ
20 | 音声出力 | 1.2W/5W （抵抗定数の変更で可能）
21 | ライン出力 | ライン出力にAMP+SPにてVRｘを可変して確認 |  |  |  |  | レ
22 | VR1
23 | VR2
24 | VR3
25 | VR4
26 | -6ｄB減音
27 | -14ｄB減音
28 | -6ｄB減音保持 | 電源OFF⇒電源ON
29 | -14ｄB減音保持 | 電源OFF⇒電源ON
30 | 外部VRコネクタ
31 | LINEコネクタ
 | デバッグ機種設定 | 本番
 | SW7 6 | MS２，MS1
 | OFF OFF：5A2 | OP OP | 各モードでの確認による |  |  |  | レ
 | OFF ON :5F2 | OP CL |  |  |  |  | レ
 | ON OFF:5F1 | CL OP |  |  |  |  | レ
 | ON ON :65CIH02（5F9） | CL CL |  |  |  |  | レ

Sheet: 5A2
IHE8001 チェック事項
 |  |  |  |  |  | チェック
 | 5A2 再生モード 3，２，１ 取説参照のこと 接点8bit | 000通常再生 | Jernej | インターバルタイマ無 one-shot: 1回再生 レベル入力：リピート再生 |  | OK
 |  |  | Jernej | インターバルタイマー有 0 s 30 s 60 s 120 s 再生終了後タイマー動作 動作中SW無視 STOP有効 |  | OK
 |  | 001後入力切替再生 |  | インターバルタイマ無 one-shot only、レベル入力：なし SW入力中のみ繰り返し含み再生 SWが切れるとSTOP相当 |  | OK
 |  | 010優先順位再生 | Jernej | インターバルタイマ無 one-shot 1回 Levelリピート連続 即座に変更 優先処理 SW1 > SW2 > SW3 > … > SWn |  | OK
 |  | 011入力中再生 | Jernej | インターバルタイマ無 one-shot無 SW入力中のみ繰り返し含み再生 SWが切れるとSTOP相当 |  | OK
 |  | 100バイナリ制御 ３(負論理） | Jernej | バイナリ制御３ 6650V2互換 1-126; 20 ch 保持 1 = 7Eh - SW1以外、全部押されている STOP: 7Fh, 00h | DIP-SWの減音はなし | OK
 |  | 101予備 | Jernej | 予備 |  | OK
 |  | 110バイナリ制御 1(負論理） | Jernej | バイナリ制御１ 1-250; 20 ch 保持 BUSY LOW 1 = FAh STOP: FFh, 00h |  | OK
 |  | 111バイナリ制御 ２(正論理） | Jernej | バイナリ制御２ 1-250; 20 ch 保持 BUSY LOW 1 = 01h STOP: FFh, 00h |  | OK
 |  | 共通事項 |  | 再生中 STOP 入力で再生停止 （バイナリーモード中、停止コマンドでも共通） BUSY ON(L)

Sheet: 5F2
IHE8001 チェック事項
 |  |  |  |  |  | チェック
 | 5F2 | 000通常再生 | Jernej | インターバルタイマ無 one-shot: 1回再生 レベル入力：リピート再生 | →WAV5A2と同じ | OK
 |  |  | Jernej | インターバルタイマー有 0 s 30 s 60 s 120 s 再生終了後タイマー動作 動作中SW無視 STOP有効 | →WAV5A2と同じ | OK
 |  | 001後入力切替再生 | Jernej | インターバルタイマ無 one-shot only、レベル入力：なし SW入力中のみ繰り返し含み再生 SWが切れるとSTOP相当 | →WAV5A2と同じ | OK
 |  | 010優先順位再生 | Jernej | インターバルタイマ無 one-shot 1回 Levelリピート連続 即座に変更 優先処理 SW1 > SW2 > SW3 > … > SWn | →WAV5A2と同じ | OK
 |  | 011入力中再生 | Jernej | インターバルタイマ無 one-shot無 SW入力中のみ繰り返し含み再生 SWが切れるとSTOP相当 | →WAV5A2と同じ | OK
 |  | 100予備 |  |  |  | OK
 |  | 101バイナリ制御 A(負論理） | Jernej | バイナリ制御３ 6650V2互換 1-126; 20 ch 保持 1 = 7Eh - SW1以外、全部押されている STOP: 7Fh, 00h | 最上位biｔ(bit7）無視すれば →WAV5A2と同じ | OK
 |  | 110バイナリ制御 1(正論理） | Jernej | バイナリ制御1 1-255; 20 ch 保持 BUSY LOW 1 = 01h STOP: FFh, 00h | STOPコマンドのコードが異なる →他はWAV5A2と同じ | OK
 |  | 111バイナリ制御 ２ (負論理） | Jernej | バイナリ制御2 1-255; 20 ch 保持 BUSY LOW 1 = FAh STOP: FFh, 00h |  | OK
 |  | 共通事項 |  | 再生中 STOP 入力で再生停止 （バイナリーモード中、停止コマンドでも共通） BUSY ON(L)

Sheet: 5F1
IHE8001 チェック事項
 |  |  |  |  |  | チェック
 | 5F1 入力bit数 4 | 000通常再生 | Jernej | インターバルタイマ無 one-shot: 1回再生 レベル入力：リピート再生 | →WAV5A2/５F2と同じ | OK
 |  |  | Jernej | インターバルタイマー有 0 s 30 s 60 s 120 s 再生終了後タイマー動作 動作中SW無視 STOP有効 | →WAV5A2/５F2と同じ | OK
 |  | 001後入力切替再生 | Jernej | インターバルタイマ無 one-shot only、レベル入力：なし SW入力中のみ繰り返し含み再生 SWが切れるとSTOP相当 | →WAV5A2/５F2と同じ | OK
 |  | 010優先順位再生 | Jernej | インターバルタイマ無 one-shot 1回 Levelリピート連続 即座に変更 優先処理 SW1 > SW2 > SW3 > … > SWn | →WAV5A2/５F2と同じ | OK
 |  | 011入力中再生 | Jernej | インターバルタイマ無 one-shot無 SW入力中のみ繰り返し含み再生 SWが切れるとSTOP相当 | →WAV5A2/５F2と同じ | OK
 |  | 100予備 | Jernej | 予備 |  | OK
 |  | 101予備 | Jernej | 予備 |  | OK
 |  | 110予備 | Jernej | 予備 |  | OK
 |  | 111予備 | Jernej | 予備 |  | OK
 |  | 共通事項 |  | 再生中 STOP 入力で再生停止 BUSY ON(L)

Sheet: 65CIH02（5F9）
IHE8001 チェック事項
 |  |  |  |  |  |  | チェック
 | 5F9 納入仕様書 WAV5F9-IH00.pdf 65CIH02仕様書_IUK.PDF 両方を参照のこと 接点12bit | 000通常再生 | Jernej | ONSHOT only 立ち下がり15ms（50msでない） 再生途中でも後入力CHに即座に切替 ﾚﾍﾞﾙ入力された場合1回再生し、待ち状態とする。 WPJ内の音量選択あり | →WAV5A2/５F2 後入力切替再生と類似 | 65CIH02（5F9基板使用） 入力BIT数=12 SP出力は打合による8W⇒5W MODE1：通常再生 MODE２：専用バイナリ ・制御信号はすべて、チャッタ処理実データ15ms（仕様では7ms） ・STBは立下り検出 | OK
 |  | 001専用バイナリ制御 | Jernej | 負論理 5F2の制御2と同じ。Ｃｈ：255 STOP: FFh, 00h バッファリング20ｃｈ保持 減音なし |  |  | OK
 |  | 010予備 | Jernej | 予備 |  |  | OK
 |  | 011予備 | Jernej | 予備 |  |  | OK
 |  | 100予備 | Jernej | 予備 |  |  | OK
 |  | 101予備 | Jernej | 予備 |  |  | OK
 |  | 110予備 | Jernej | 予備 |  |  | OK
 |  | 111予備 | Jernej | 予備 |  |  | OK
 |  | 共通事項 |  | 再生中 STOP 入力で再生停止 BUSY ON(L)

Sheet: Sheet2
TB1 | 1 | 2 | 3 | 4 | 5 | 6 | 7 | 8 | 9 | 10 | 11 | 12 | 13
接点 | +SP | -SP | GND | 1 | 2 | 3 | 4 | 5 | 6 |  |  | ＊BUSY | ＊ALM
バイナリ |  |  |  | 0 | 1 | 2 | 3 | 4 | 5 | STOP | STB
基板J1 | 3 | 4 | 16 | 5 | 6 | 7 | 8 | 9 | 10 | 14 | 13 | 15 | 17
J2
TB2 | 1 | 2 | 3 | 4 | 5 | 6 | 7 | 8 | 9 | 10 | 11 | 12 | 13
接点 | 7 | 8 | 9 | 10 | 11 | 12 | -DC |  | +DC | STOP
バイナリ | 6 | 7 | × | × | × | × |  | × |  | × | × | × | ×
基板J1 | 11 | 12 |  |  |  |  | 2 |  | 1
J2 |  |  | 1 | 2 | 3 | 4

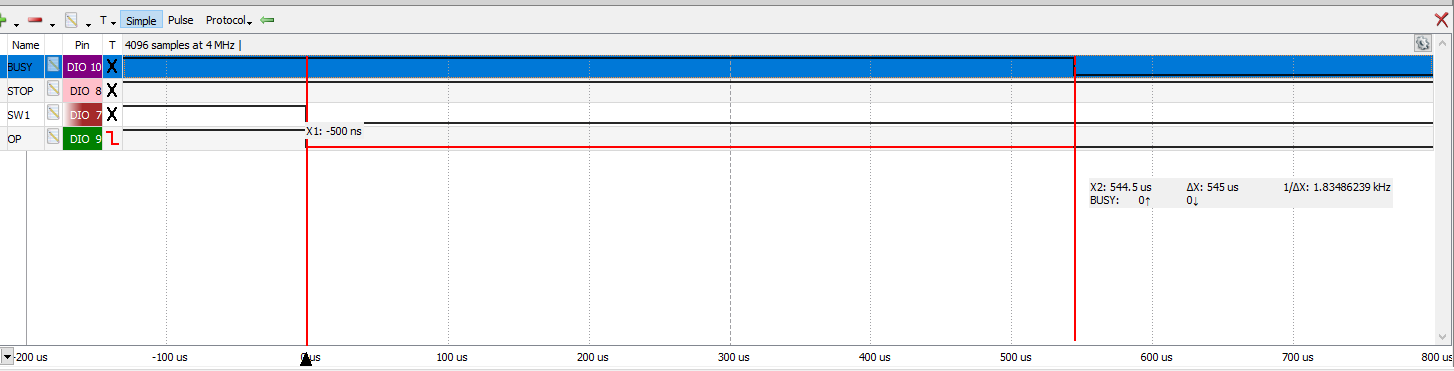
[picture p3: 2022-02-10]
Tests/Trigger_timing_5F9.png

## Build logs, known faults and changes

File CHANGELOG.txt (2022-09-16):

v3.9 / 2022-09-16 16:45:28 +0900:
- log: Version update - v3.9
  
- bug: 5A2,5F1,5F2 inputPlay mode #83
  Reverted changes and implemented the correct stop condition.

- bug: 5F9 lastInputInterruptPlay_5F9IH mode #84
  Changed already_pressed_mask variable from uint8_t to uint16_t.

v3.8 / 2022-09-07 17:13:50 +0900:
- log: Version update - v3.8
  
- bug: USB_LED #81
  After data copy from USB to flash is finished, goto while(1) loop regardless of NAND_WRITE status. If write was success, start led success pattern, otherwise error pattern.

- enh: faster polling time for 5F9 board.
  Forgot to remove LED_USBToggle().

- enh: faster polling time for 5F9 board.
  Polling time changed from 3,5 ms to 2,5 ms.

- bug: 5F9 normal play mode not working #35
  Do not interrupt the same channel. Interrupt only different channels.

v3.7 / 2022-08-31 09:26:14 +0900:
- log: Version update - v3.7
  
- bug: double scan on all pins in binary mode
  Previously only GPIOB had debounce feature. Now both GPIOB and GPIOA have debounce feature.

v3.6 / 2022-08-30 12:30:20 +0900:
- log: Version update - v3.6
  
- bug: No debounce in binary play mode #80
  Forgot to commit come files.

- test: updated 50ms pulse test case.
  
- bug: No debounce in binary play mode #80
  Different debounce time for 5F9 board. No more interrupt, just polling.

- bug: No debounce in binary play mode #80
  Implemented debounce on GPIOB (GPIO mux). In binary mode, only STOP and STB pins are effected by debounce. SW1 to SW8 are not.

v3.5 / 2022-08-24 12:40:30 +0900:
- log: Version update - v3.5
  
- bug: Problems with debounce #79
  Reverted changes from commits: fb99b7e43ed17c6dd3ab5cf8e45db1de0d2adf7f and 75be721b1dd858583bdb0bc5dac36ead643cbca6. New mechanism for detecting 2 consecutive pulses on all channels.

- bug: Problems with debounce #79
  Changed polling frequency 60 -> 65 Hz. Changed TUP0 interrupt priority from 15 to 13. Minor bug fixes in lastInputInterruptPlay().

v3.4 / 2022-08-17 15:41:49 +0900:
- log: Version update - v3.4
  
- bug: last input interrupt play multi input fix
  Multi input wasn't working. Only 1 or 2 switches were working. Now, you can press all the switches and only the last pressed channel will play.

- bug: Normal play mode - scanning next switch #75
  During level play, if switch(es) are pressed, and STOP in introduced, start playing last played channel after stop is released.

- bug: FIFO queue 5 slots #74
  FIFO queue status did not reset if STOP signal was pressed. Fixed.

- bug: Stereo file error - busy signal stays on #73
  PIN_ShutdownReset() wasn't called if stereo or wave file error occurred. Fixed.

- bug: Input play not working as expected #77
  Play mode adjusted according to specifications. Also found a bug when song play is interrupted - busy signal didn't go to off state.

- bug: Debounce on individual channel #76
  Always check switch status 3 times, when first input signal comes.

- bug: Debounce on individual channel #76
  Any switch must be pressed for 3 consecutive scans. If on first and last scan a the same switch is pressed, we assume that pulse is long enough (50 ms or more) and go into play mode.

- bug: Normal play mode - scanning next switch #75
  Example: if CH1 was played and stopped, next time SW1 and SW2 are pressed simultaneously, CH2 should start playing. Before the fix, CH1 started playing.

- bug: FIFO queue 5 slots #74
  When FIFO is full, it has to wait 5 slots until we can put data in again.

- bug: Stereo file error - busy signal stays on #73
  Only LED turned off when stereo file error was called. Forgot to also turn off busy pin. Fixed.

- bug: Short files - busy signal always on #71
  If file size is shorter than buffer size, read only file size.

v3.3 / 2022-07-28 15:16:06 +0900:
- log: Version update - v3.3
  
- enh: better error detecting of faulty wave files.
  If "fmt " or "data" chunk sizes are zero, throw error.

- enh: Not FAT format error message #69
  Changed error status to wave file error.

v3.2 / 2022-07-26 16:37:32 +0900:
- log: Version update - v3.2
  
- bug: ERR check #63
  Improved checking if USB flash drive has correct file system or not. Also, some error messages were wrong.

- bug: Error status not showing on bad wave file #62
  When creating CMT timer, the same channel was auto chosen for I2C polling and for errors. Errors now have fixed CMT channel - 3.

- Revert "enh: Processing when an error occurs #52"
  This reverts commit e224e53f1f13ccd0e31e0ad02e26d572b203eecf.
Resetting error only resets LEDs. It happens after new input signal is detected (any channel or stop signal).

Implemented better wave file error detection. If file is partially corrupted, if by the time we reach end of file we don't get fmt and data chunk info, error flag is set.

v3.1 / 2022-07-19 15:31:39 +0900:
- Licence and version update.
  
- doc: Changelog #60
  Added txt changelog and script for generating it.

- bug: Binary 7 bit mode #59
  In binary 7-bit mode, ignore MSB. Look just at 7 LSBs - example 0x95 == 0x15.

v3.0 / 2022-07-13 16:31:09 +0900:
- bug: Issue with binary FIFO queue #57
  Few bugs were left after changing to FIFO queue.

- enh: Custom fmt chunk #49
  Improved parsing of WAVE file header. It should only get the information we need, regardless of number of chunks, and ignore other chunks.
Previously parsing was limited to fixed, 44 byte header. Improved parsing so it checks for the correct chunk and fetches only data that is needed.
No more fixed "fmt " chunk size.

- bug: Does not play with 3ch simultaneously #55
  Fixed Normal Play mode. It now supports all switches being pressed simultaneously.

- bug: Issue with binary FIFO queue #57
  Changed binary play mode to have FIFO queue. Previous specs were to have normal queue while playing.

- bug: Only 460ms of audio data of 500ms is played #56
  DMA was stopped before all the data could be output. Introduced wait loop to wait for DMA to finish everything.
Removed forgotten test code (LED_USBOff).
Disabled I2C polling after data is copied from USB.

- bug: Switch debounce - chattering #54
  If to consecutive scans (20 ms) show pressed button, we assume that a button is pressed.

- Gitgnore update.
  
- enh: Processing when an error occurs #52
  If any error is detected, MCU goes to infinite while loop. MCU can be reset (software reset) if STOP is pressed.

- bug: Pressing STB while STOP is pressed results in BUSY LED blink #58
  Inside binary play modes, when checking if stop is pressed, return from function if pressed. Previously it didn't return.

- bug: Audio file size #53
  NAND flash size was set to 2 Gbit, but actual flash size is 4 Gbit. Changed flash size.

- enh: Enabled DAC amplifier.
  
- bug: One count is missing when playing a WAVE file #50
  When fixing issue #40, round buffer check was shortened by 1 count.
To fix the current bug, round buffer check was restored and buffer size increased.
When 8-bit song is played, only half of the buffer is used.
When 16-bit song is played 1/4 of the buffer is used.

v2.0 / 2022-06-13 15:23:00 +0900:
- changelog: Included FW version in VoiceNaviMain.c
  
- bug: Ignore 8-bit data on 7-bit play mode
  Instead of ignoring just 7th bit, ignore all channels that are bigger than 127 (7-bit).

- bug: Input play mode doesn't cut the song #47
  Inserted detection if 2 signals are set at the same time. After double input, break the song playing and play the input that is still set.

- bug: Normal play mode channels should not alternate #46
  Reset previously pressed switch only if input is released. If input is pressed, remember previously pressed switch.

- bug: On interval delay watchdog timer triggers #45
  Because program was holding in while loop, watchdog timer reset the program. Added WDT reset into holding loop.

- bug:  Weird sound output on channels 9 to 12 #44
  Bug fixed. uint16_t value was going into uint8_t variable.

- enh: Watchdog implementation #43
  Implemented WDT. It starts automatically on power on. Period is about 522 ms.

- bug: Interrupt play was stuck in infinite loop.
  If forcefully stopped (interrupted), DMA buffer address wasn't reset. Added reset address.

- bug:  WPJ file corruption not detected #41
  Implemented full file corruption detection. If random file has extension wpj, error will be shown.

- bug: Non exclusive errors to exclusive errors
  Created exclusive errors. If one error happened before other, some weird blinking would occur. This is now fixed. First error has priority, further errors are not displayed.

- bug: Flash management for playlist table.
  Configured flash management for playlist table. If corrupted blocks are in beginning of flash, those blocks are skipped and data is written to next available block.

- bug: Output sound is cut at the beginning #40
  8-bit audio was stuck in first loop when filling play buffer. Fixed.

- bug: Output sound is cut at the beginning #40
  Fixed cut sound at start. Reduced delay from start signal to actual playback.

- bug: Popping sound #39
  Fixed bug introduced with commit: ac1170cda641362c732f92e4deb73e2e657df66c

- hw: New hardware revision.

v1.5 / 2022-04-08 17:40:53 +0900:
- enh: Change errors table #36
  Changed LED error states. Updated readme file with new table.

- bug: Skipping bad blocks not working #37
  Fixed address counting if bad sectors are skipped. Added flash overflow check.

- bug: Negative Busy signal on 5A2 #33
  Added condition statement to change pin polarity if 5A2 board and positive 8-bit binary mode is selected.

- bug: Binary modes play range #34
  Extended number of playable channels.

- bug: 5F9 normal play mode not working #35
  Bug is now fixed, introduced in 45fcea581293f8e339a4f3677873bf2401642c7a.

v1.4.2 / 2022-04-01 14:35:43 +0900:
- bug: Data from USB are copied on startup
  If empty flash and USB inserted, error showing empty flash would appear before copying data from USB to flash. Fixed bug.

- Binary mode channel select, address, and stop command #32
  Updated error table

- Binary mode channel select, address, and stop command #32
  Error if stereo file is being played. Playmode code refactoring.

- Fix #31 - changed binary STOP signal. Added check for mono and stereo sound.
  
- Data from USB are copied on startup. No more live copy with DIP switch 7.

v1.4.1 / 2022-02-16 14:58:28 +0900:
- VR3 and VR4 volume controls are only available on 5F9IH board. Fixed wrong board detection.

v1.4 / 2022-02-15 15:21:45 +0900:
- Final code updates before delivery.
  
- e2 studio update. Needed to change some source files because of API update.
  
- Updated workspace settings.
  
- Set I2C speed to 384 kHz (max for CPU).
  
- Switched MS1 and MS2 pins.

v1.3 / 2022-02-08 10:41:18 +0900:
- Issue #29 - forgot to rebuild and push the newest binaries.
  
- Fix #29 - implemented IRQ instead of polling for 5F9 binary play mode.
  
- Updated check list.
  
- Revert "Updated checklist. Removed wrong error commit."
  This reverts commit 81bca6530918ca1b92192c37c72127dd9cf83017.

- Updated checklist. Removed wrong error commit. Don't add new files! Save changes to current file and commit it!
  
- Ref #28 add file IHE8001 MODEチェック4機種チェック1115.xlsx　

v1.2 / 2021-11-12 11:29:10 +0900:
- Fix #27 - to enter into debug mode, solder JP1. If left opened, normal operation mode is selected.
  
- Merge branch 'main' of https://github.com/AZURTEST-CORP/VoiceNavi
  
- Fix #22 - Changed play mode. On channel 0, play mode for 5F9 is last input interrupt play.
  
- Updated checklist. Removed wrong error commit.
  
- Add files via upload
  
- Issue #13 - binary mode stops immediately if 0x00 or 0xFF is received.
  
- Issue #13 - reverted positive and negative binary modes.
  
- Updated check list.
  
- Issue #17 - stop GPIO polling while copying to NAND flash.
  
- Issue #20 - 0xFA is 1 in negative binary 250 mode
  
- Test commit.
  
- Updated check sheet.
  
- Updated chapters 8 and 9 in system specs.
  
- Updated check list.
  
- Shut down sound and turn it on before play.
  
- Hardware revision 1.

v1.1 / 2021-10-04 14:48:49 +0900:
- Updated Readme.
  
- Added support for 5F9IH. Modified some existing play modes.
  
- Updated Readme. Added test files and specification files.
  
- Minor bug fixes.
  
- Fix #7 - USB LED blinks after copy from USB to flash is done. Added support for VR3 and VR4 volume control.

v1.0 / 2021-09-28 16:56:13 +0900:
- Added support for 5F1 and 5F2 board. Issue #13 - switched positive and negative logic for binary mode.
  
- Issue #16 - priority mode has also level play, not only one shot.
  
- Code refactoring 4.
  
- Code refactoring 3.
  
- Code refactoring 2. Fixed deadlock in inputPlay mode.
  
- Issue #14 - if undefined song is played, interval timer doesn't start.
  
- Issue #16 - priority play interrupts same level of priority of higher.
  
- Issue #13 - fixed positive and negative logic for binary modes.
  
- Issue #16 - same switch can interrupt same song.
  
- Code refactoring 1.
  
- Issue #13 - reversed positive and negative binary play mode.
  
- Issue #11 - STOP signal stops play also during repeated or combined songs.
  
- Issue #14 - during interval wait time, LED and BUSY signals are set.
  
- Issue #15 - during interval wain, don't put songs into play queue; fixed.
  
- Issue #16 - fixed to one shot input.

v0.3 / 2021-09-22 16:06:00 +0900:
- Forgot to add elf file to commit 4e2261532a9b5b076a7a5450acdf9d47f16603ce
  
- Restart from STOP with binary play mode - fix.
  
- Fix #8 - moved mode reading to interrupt routine from main. Improved handling for binary play modes.
  
- Fix #9 - Inverted read inputs for DIP switch.

v0.2 / 2021-09-13 13:15:31 +0900:
- Enabled USB lED, to see when copying started and ended.
  
- Readme edit, commented out LED_USBToggle.
  
- Added new specs for 5A2.

v0.1 / 2021-09-09 15:01:59 +0900:
- Added comment.
  
- Fixed bug in bit order.
  
- Erase flash after checking for FAT and .wpj file.
  
- Flash - always wire on new page. Don't write on same page twice.
  
- Issue #6 - reverted. Popping sound is HW problem.
  
- Issue #4 - volume reduction is saved to NAND flash for binary play mode.
  
- Fix #5 - busy signal shows on output. Reduced sampling time for GPIO pins to 20 ms (50 Hz).
  
- Added licence and readme.
  
- Added licence
  
- Issue #4 - implemented saving volume reduction to NAND Flash.
  
- Removed Demo project.
  
- Moved to VoiceNavi folder.
  
- Fix #3 - interval play implementation.
  
- NAND flash small changes - should fix incorrect writings to flash.
  
- Issue #2 - All binary play modes implementation.
  
- Issue #2 - Input play mode implementation.
  
- Issue #2 - Priority play mode implementation.
  
- Issue #2 - Last input play mode implementation.
  
- Issue #2 - Normal play mode; code refactoring.
  
- Issue #2 - Normal play mode implementation.
  
- Minor bug fixes.
  
- Added checklist.
  
- Refactoring and visual code editing.
  
- Fix #1 - applied DMA for playing sound. Can play 8-bit and 16-bit, only mono sound.
  
- Fix #2430 - button debounce fix. Implemented 45 ms sampling.
  
- Fix #2432 - real time volume control.
  
- Issue #2432 - implemented DMA for reading analog potentiometer value. Writing to digital potentiometer.
  
- Issue #2432, #2430 - I2C sending and receiving is now periodical with 22 Hz (45 ms).
  
- Issue #2434 - flash write change. Just for demo - development of other modules.
  
- Added GPIO init. Added ADC converter. Some changes to flash. Migration to RX651.
  
- Added documentation for 5A2 board.
  
- Added play modes for 5F1 board - bit mode 128.
  
- Added play modes for 5F1 board. Reverted NAND FIFO buffer.
  
- GPIO mux over I2C.
  
- FIFO buffer for reading from flash.
  
- Writing to NAND flash from USB device. Reading data from flash and playing it.
  
- NAND Flash reading and writing. Copy from USB.
  
- NAND Flash, read, write, erase operations completed.
  
- Updated FatFS library to the newest version.
  
- Prepared "Demo" for SPI NAND Flash testing.
  
- Bug fixes for audio play. Now it plays when switch is pressed.
  
- Added audio play to Full project.
  
- Added lookup tables to Full project.
  
- Changed to GCC compiler, added parsing for .wpj file.
  
- Added FatFS to the project.
  
- Added full project.
  
- WAV parser
  
- Reading and writing to flash.
  
- Uploaded e2 studio project to repository.
  
- Initial commit.

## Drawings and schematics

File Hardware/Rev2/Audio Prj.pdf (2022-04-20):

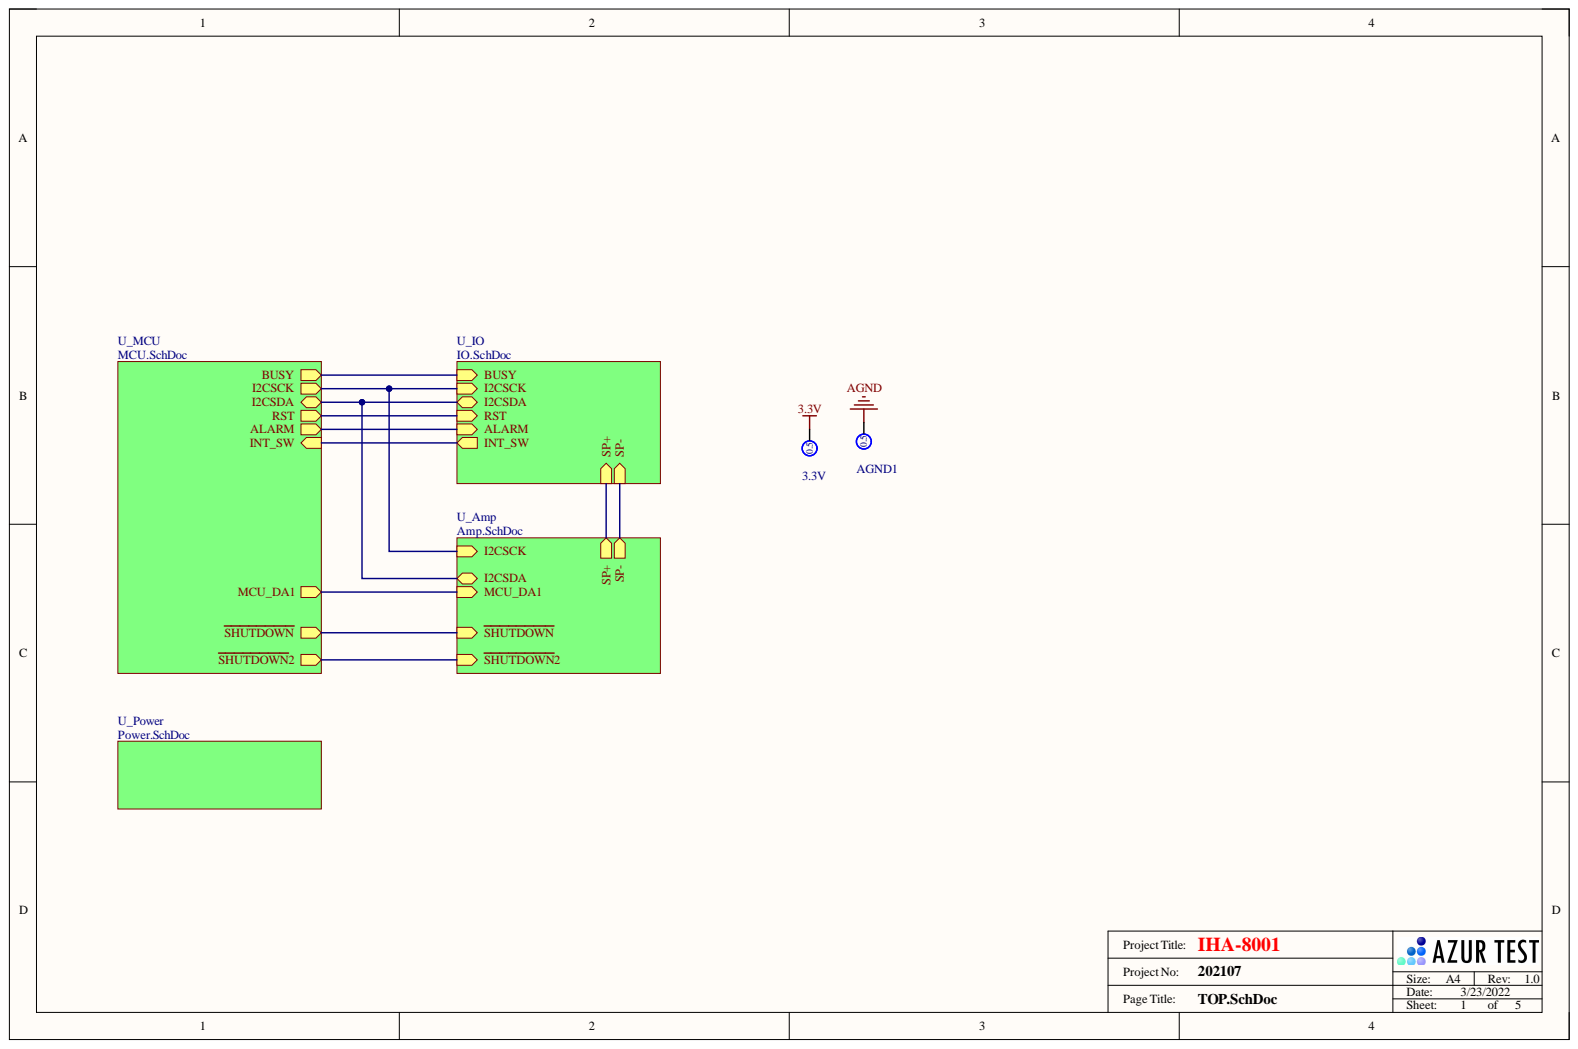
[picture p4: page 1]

Size: A4 | Rev: 1.0

Page Title: TOP.SchDoc | Date: 3/23/2022

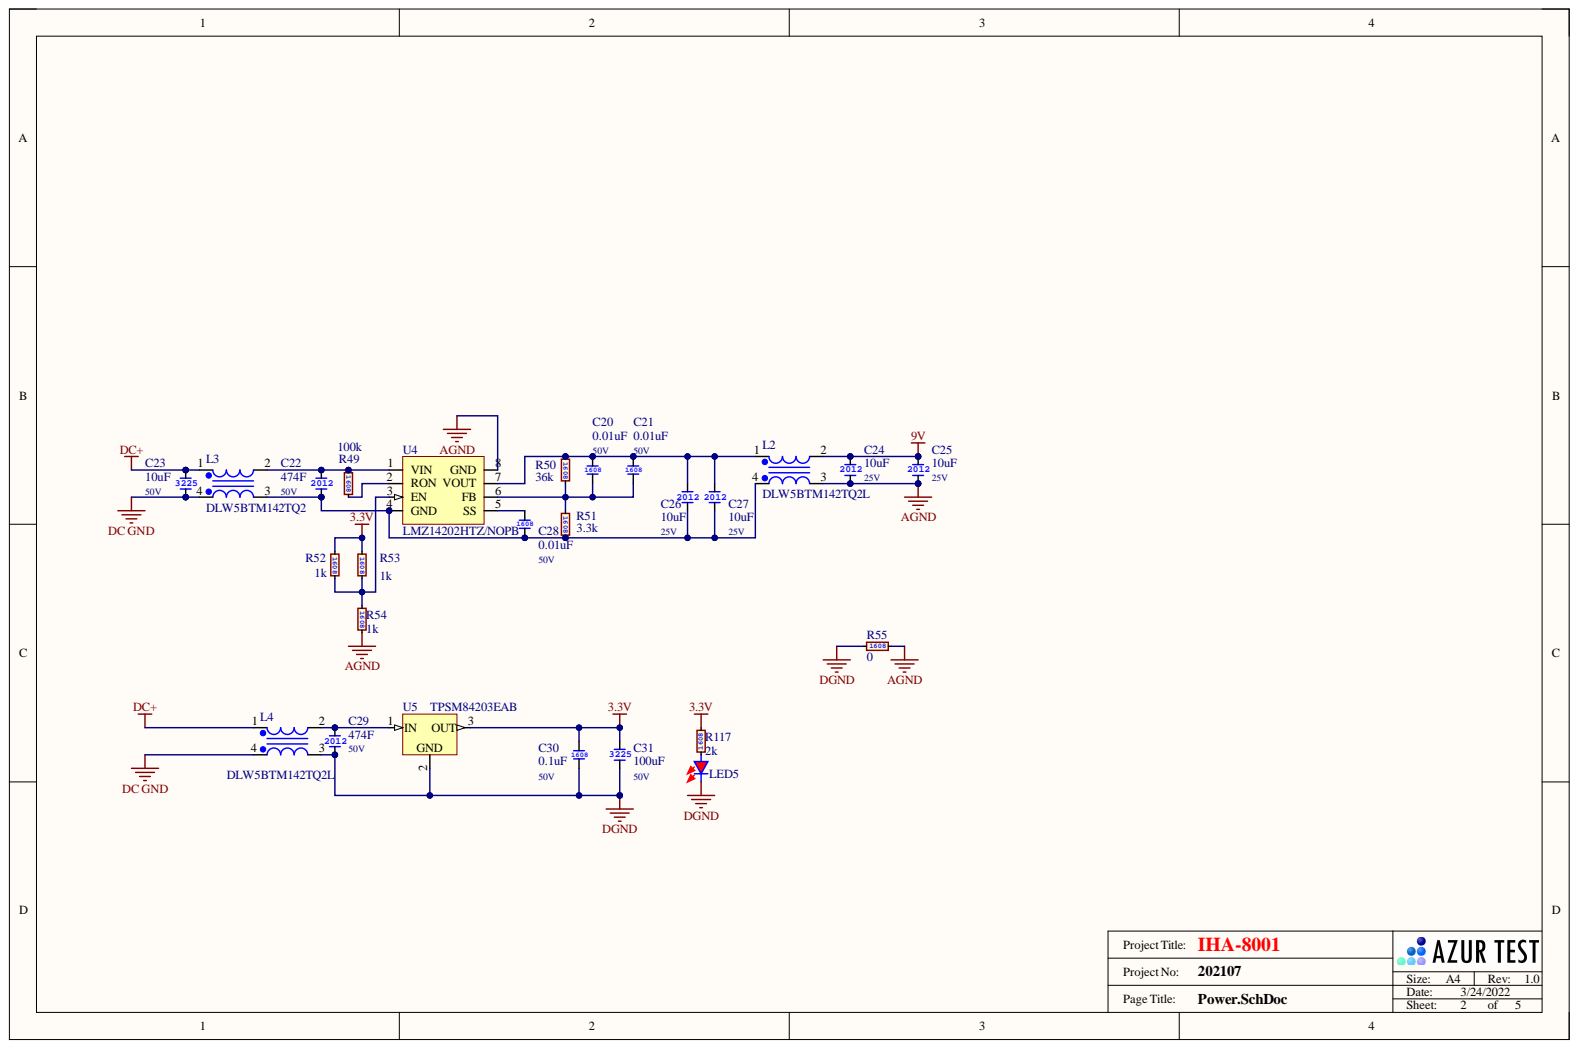
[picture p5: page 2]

Size: A4 | Rev: 1.0

Page Title: Power.SchDoc | Date: 3/24/2022

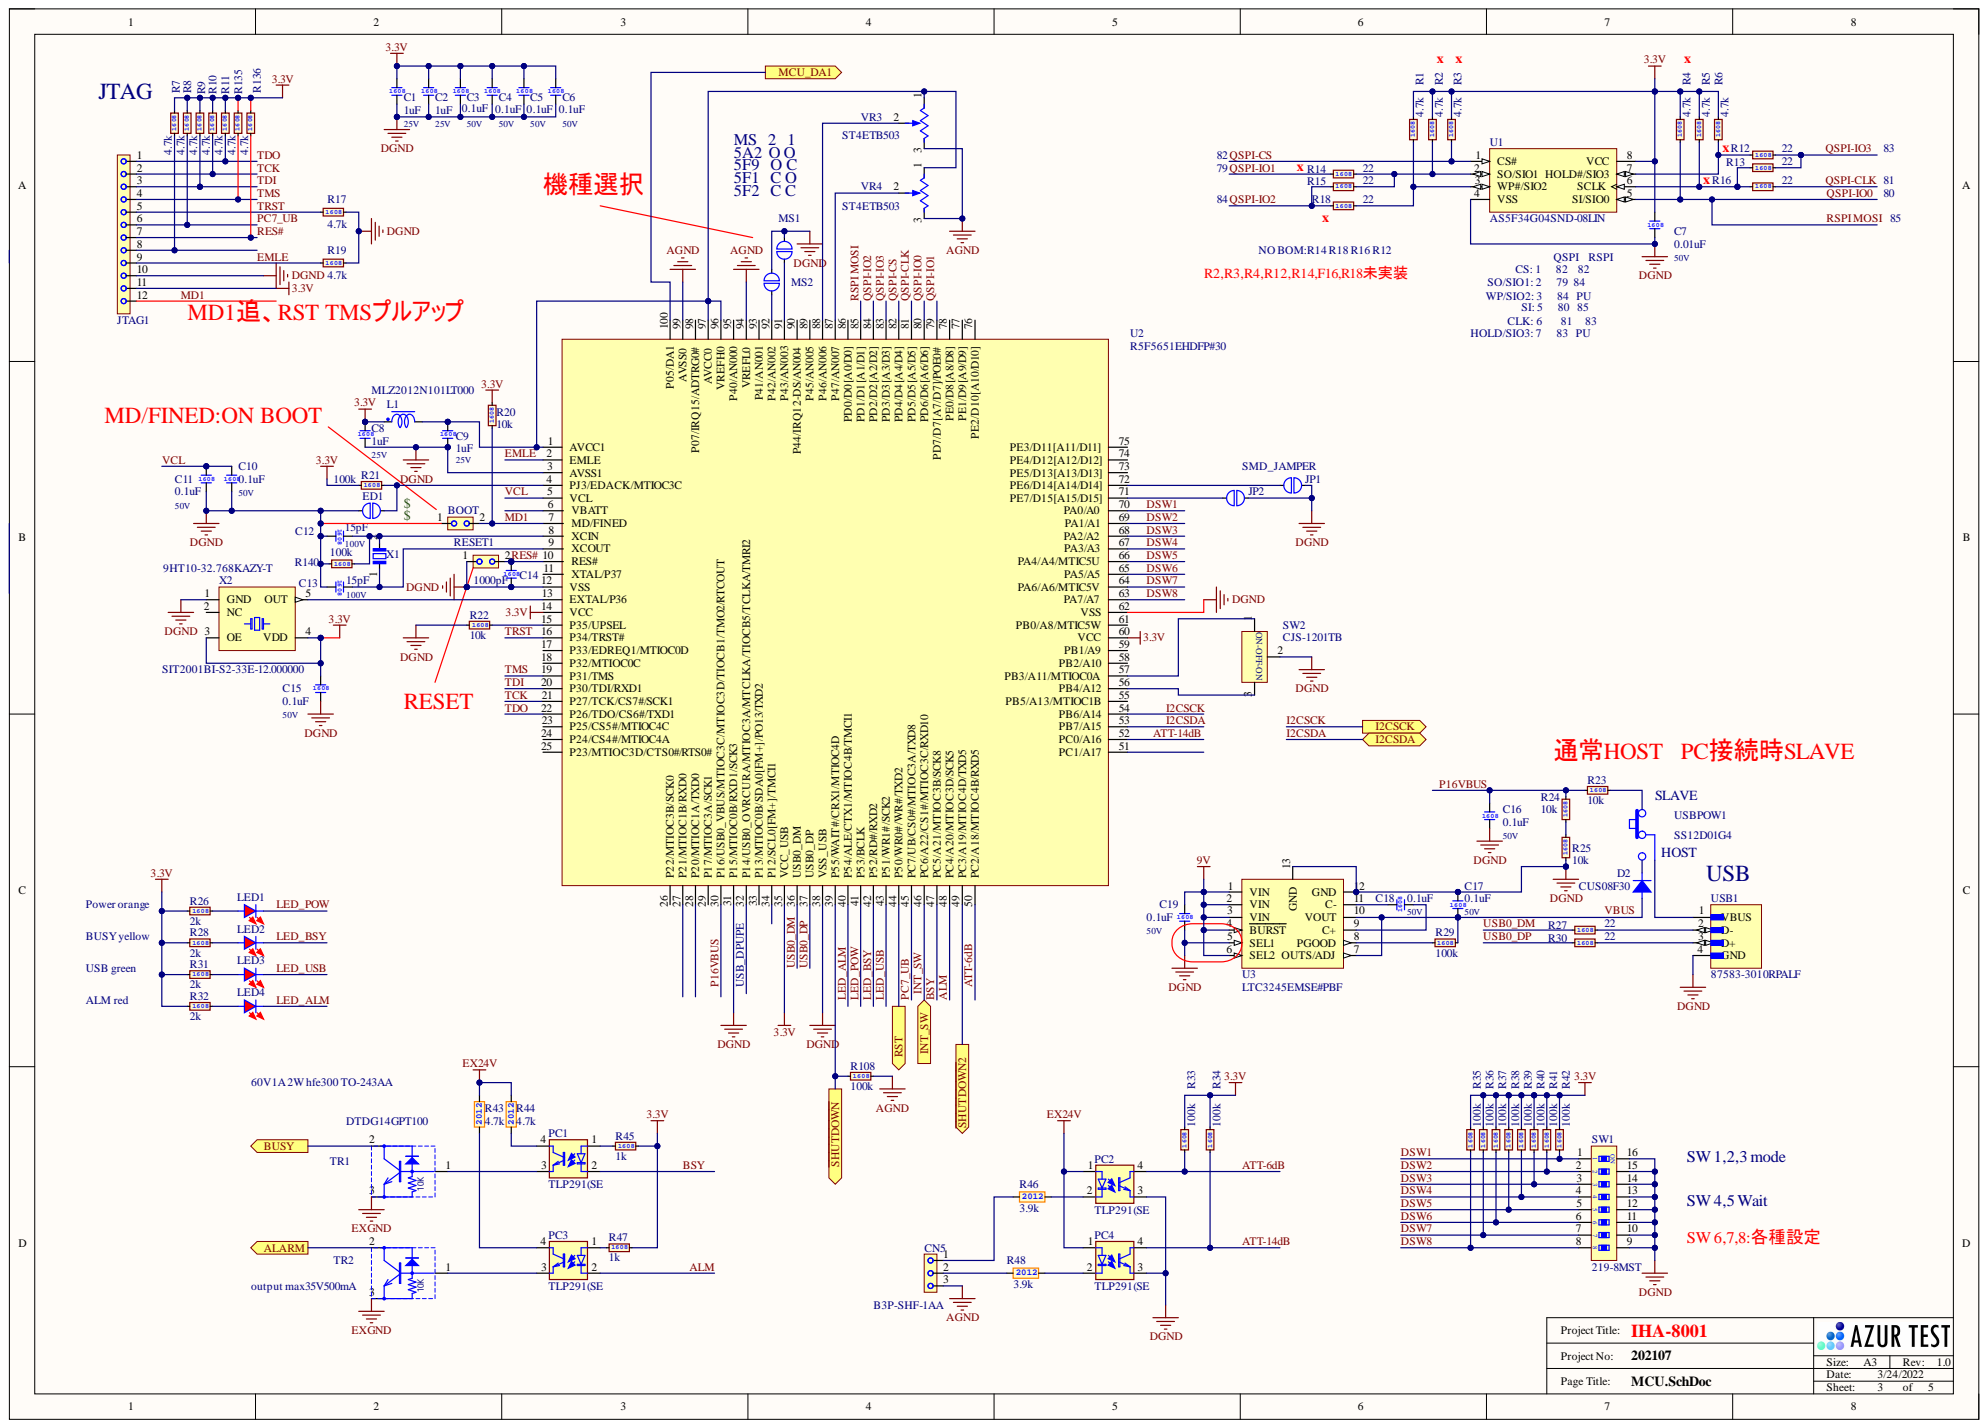
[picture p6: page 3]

ST4ETB503 VR4 2

MD/FINED:ON BOOT

AVCC1 1

EMLE | EMLE 2

OUT | 5 GND 1 100V | | EXTAL/P36 13 | DSW8

NC 2 | R22 3.3V 3.3V | VCC 14

DSW2 | 2 | 15

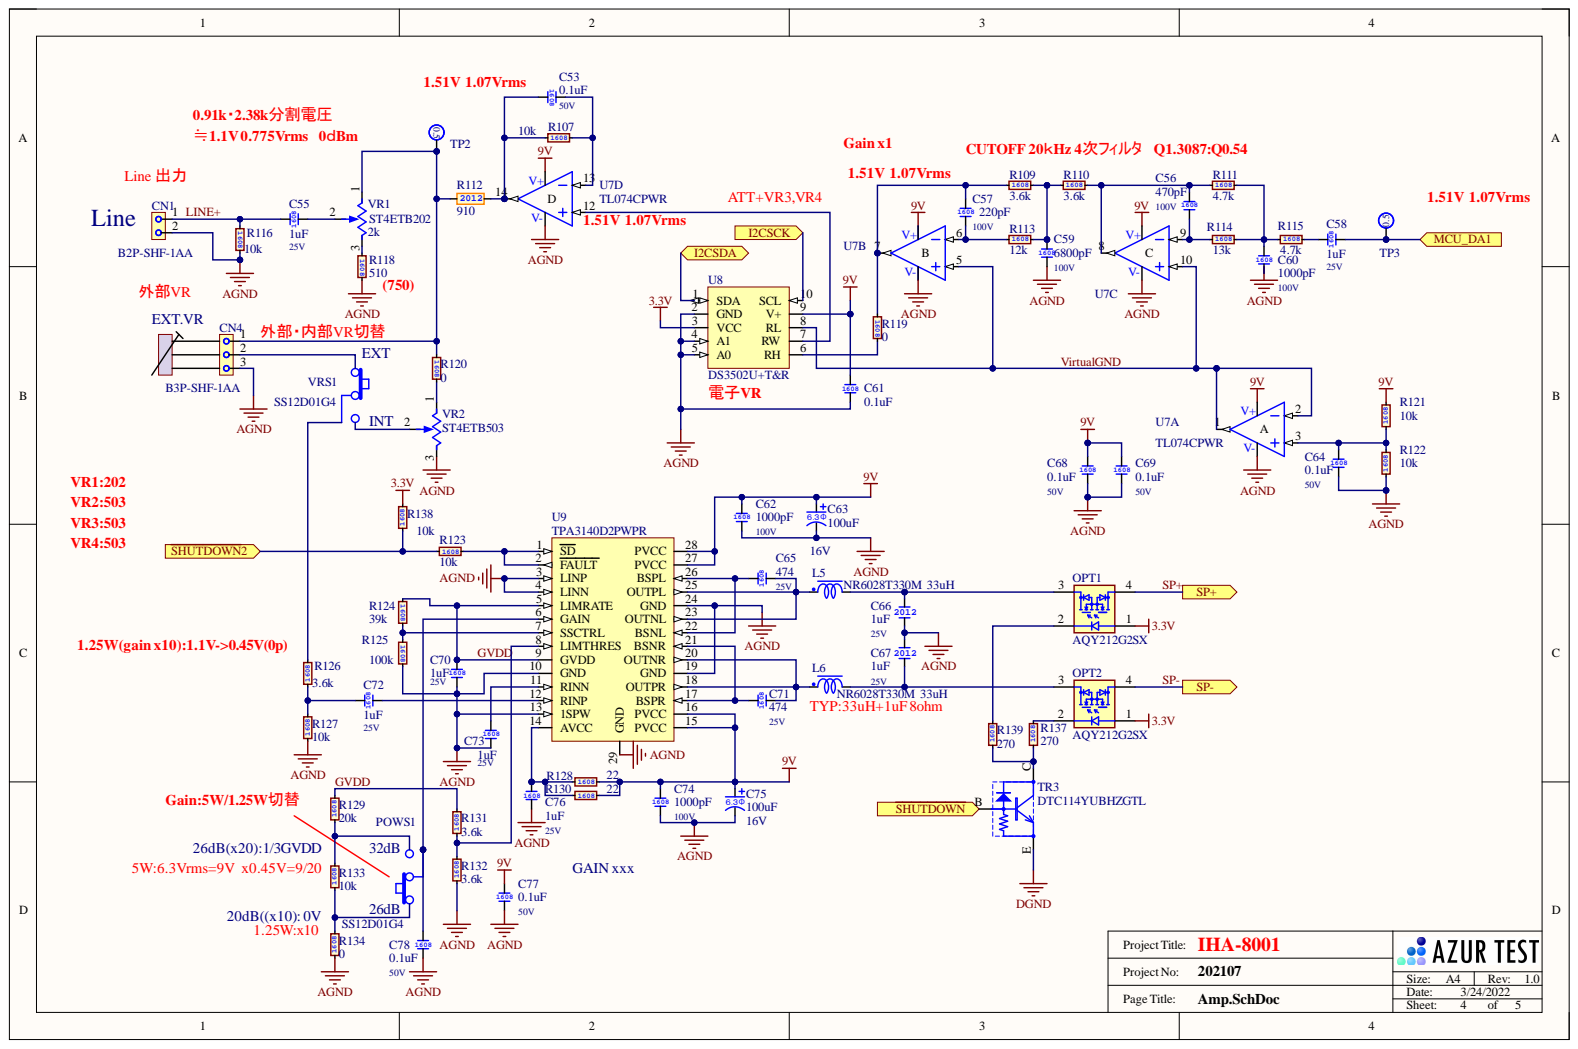
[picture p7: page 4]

GND 10

RINP 12

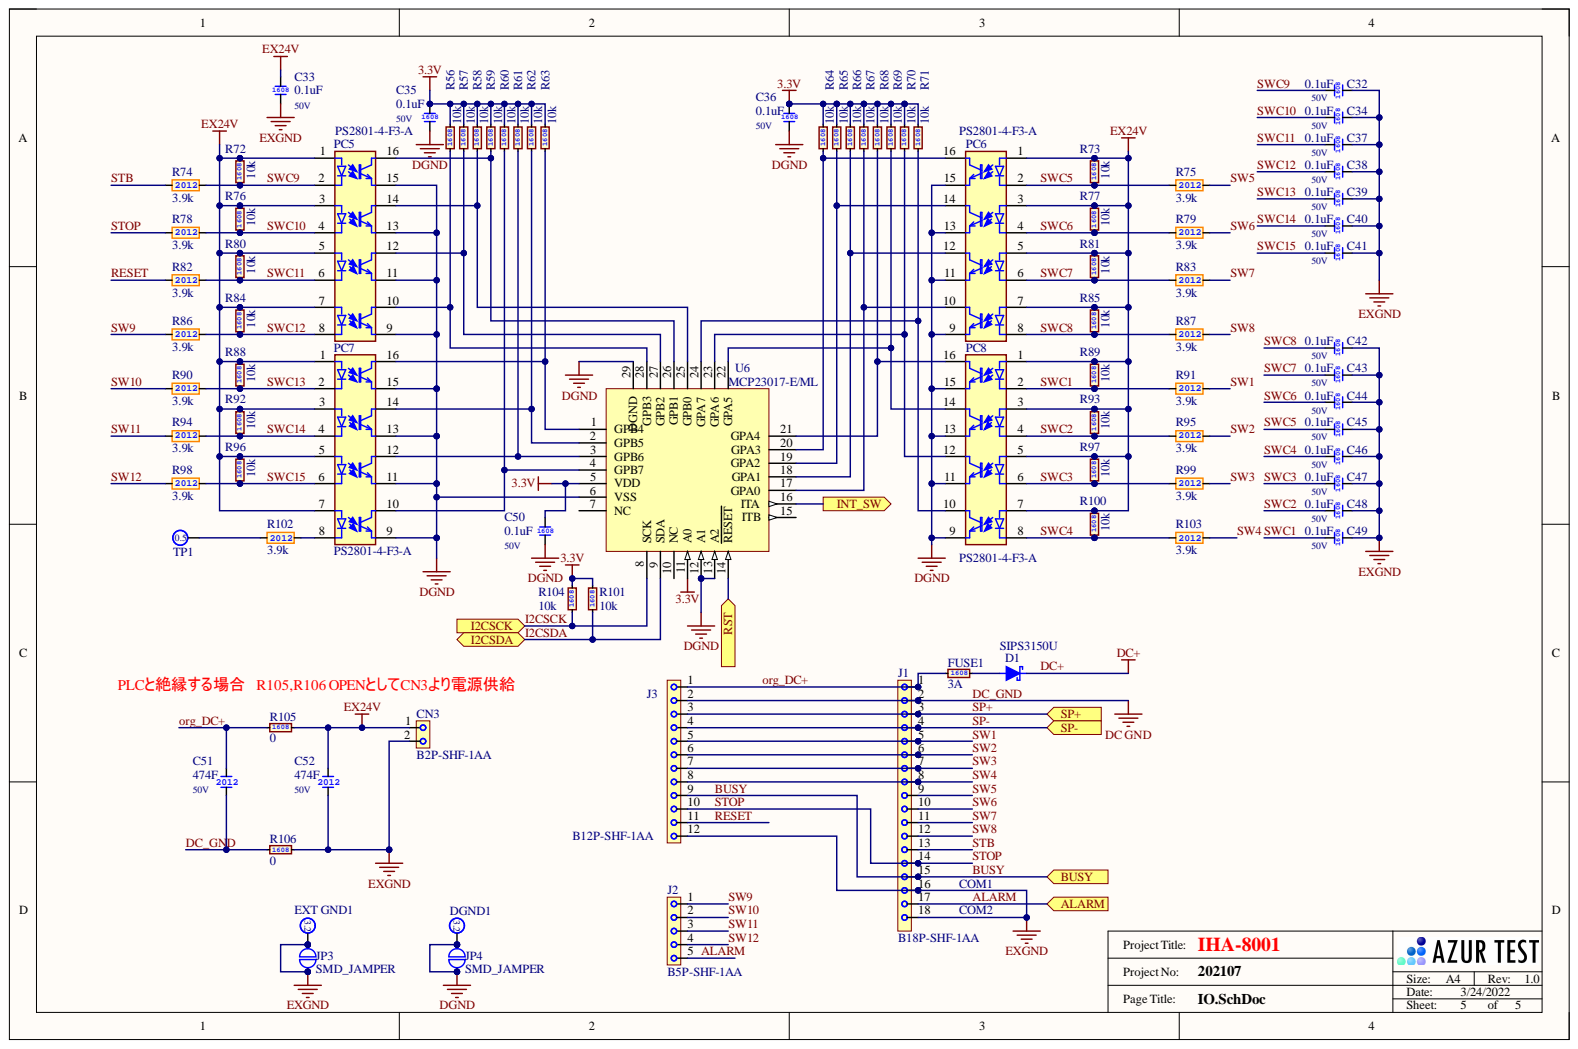
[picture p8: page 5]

VDD 5

3 | 3 SP+
4 | 4 SP-

9 BUSY | 9
10 STOP | 10 SW6 BUSY
11 RESET | 11

15
16 COM1
17 ALARM

Size: A4 | Rev: 1.0

Page Title: IO.SchDoc | Date: 3/24/2022

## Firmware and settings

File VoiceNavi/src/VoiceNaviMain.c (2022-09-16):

/**
 * Voice Navi Firmware
 *
 * MIT License
 *
 * Copyright (c) 2022 Azurtest
 *
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
 * THE SOFTWARE IS PROVIDED "AS IS", WITHOUT WARRANTY OF ANY KIND, EXPRESS OR
 * IMPLIED, INCLUDING BUT NOT LIMITED TO THE WARRANTIES OF MERCHANTABILITY,
 * FITNESS FOR A PARTICULAR PURPOSE AND NONINFRINGEMENT. IN NO EVENT SHALL THE
 * AUTHORS OR COPYRIGHT HOLDERS BE LIABLE FOR ANY CLAIM, DAMAGES OR OTHER
 * LIABILITY, WHETHER IN AN ACTION OF CONTRACT, TORT OR OTHERWISE, ARISING FROM,
 * OUT OF OR IN CONNECTION WITH THE SOFTWARE OR THE USE OR OTHER DEALINGS IN THE
 * SOFTWARE.
 */

/* Firmware version: 3.9 */

#include "globals.h"

/** Function definition */
void main(void);
void CNT_USB_CntCallback();
void CNT_IntervalDelay();
void callBack_read();
void ISR_periodicPolling();

/** Defines */
#define I2C_GPIO_ADDR 0x21
#define I2C_POTENT_ADDR 0x28

#define RINGBUF_SIZE 4096
#define p_inc(p, max) (((p + 1) >= max) ? 0 : (p + 1))

/** Global variables */
uint32_t g_binary_vol_reduction_address = NAND_VOL_PAGE;
system_status_t g_systemStatus;
uint8_t g_binary_vol_reduction;
int g_decode_putp = 0;

/** Song, play mode and output related variables */
uint8_t file_data[FILE_SIZE];
playlist_t output_music[255];
flash_custom_FAT_t flash_table[255];
wav_header_t wav_file;
uint16_t volume[2] __attribute__((aligned(4)));
uint16_t ringbuf[RINGBUF_SIZE] __attribute__((aligned(8192)));
uint8_t mode_select;
modeSelect_t boardType;

/** Communication structures */
sci_iic_info_t iic_info;
usb_ctrl_t ctrl;
usb_cfg_t cfg;
st_memdrv_info_t memdrv_info;

/** CMT counter related variables */
uint32_t cmt_channel;
uint32_t cmt_channel_usb;
uint32_t cmt_channel_i2c;
uint32_t cmt_channel_interval_delay;
int usb_cnt;
uint8_t interval_time;

static int decode_getp(void)
{
  return ((unsigned int) DMAC1.DMSAR - (unsigned int)&ringbuf[0]) / sizeof(uint16_t);
}

static int decode_put(uint16_t audio_data)
{
  int ret = 0;

  unsigned int putp = p_inc(g_decode_putp, RINGBUF_SIZE);

  if(putp != decode_getp())
  {

    ringbuf[g_decode_putp] = audio_data;

    g_decode_putp = putp;
    ret = 1;
  }

  return ret;
}

static void wav_put(void *read_buffer, uint32_t size)
{
  uint8_t *data = read_buffer;
  int16_t audio_data;

  if(wav_file.bps == 8)
  {
    for(int n = 0; n < size; n++)
    {
      audio_data = (int16_t)(*data++);
      audio_data = audio_data << 4;

      while(1 != decode_put((uint16_t)audio_data))
      {
        if(!g_systemStatus.flag_isPlaying)
        {
          return;
        }
      }
    }
  }
  else
  {
    for(int n = 0; n < size; n += 2)
    {
      audio_data = (int16_t)((*(data + 1) << 8) | *data);
      audio_data = (audio_data >> 4) + 2048;

      data += 2;

      while(1 != decode_put((uint16_t)audio_data))
      {
        if(!g_systemStatus.flag_isPlaying)
        {
          return;
        }
      }
    }
  }

}

static void emptyPlayBuffer()
{
  /* Fill buffer with 2048 (half of 12-bit ADC) for smooth transitions between songs. */
  for(int i = 0; i < RINGBUF_SIZE; i++)
  {
    ringbuf[i] = 2048;
  }
  R_DAC1_Set_ConversionValue(2048);
}

static void PIN_BusyOn()
{
  if((boardType == WAV_5A2) && (mode_select == 7))
  {
    PIN_BusySet();
  }
  else
  {
    PIN_BusyReset();
  }
}

static void PIN_BusyOff()
{
  if((boardType == WAV_5A2) && (mode_select == 7))
  {
    PIN_BusyReset();
  }
  else
  {
    PIN_BusySet();
  }
}

static void playFromPlaylist(uint8_t playNr, uint8_t isInfineteLoop)
{
  int _index = 0;
  int _fileToPlay;
  uint32_t _dataSize;
  uint32_t _sizeToRead;
  uint32_t _fileAddress;
  int _trackNr = 0;
  int _repetitions = 0;
  wav_err_t wav_err;

  if(output_music[playNr].playlist_len)
  {
    g_systemStatus.flag_isSongAvailable = 1;
  }
  else
  {
    g_systemStatus.flag_isSongAvailable = 0;
    return;
  }

  if(!isInfineteLoop)
  {
    g_systemStatus.vol_ctrl_nr = output_music[playNr].vol_ctrl - 1;
  }

  LED_BusyOn();
  PIN_BusyOn();
  /* Enable audio amp */
  PIN_ShutdownSet();
  while(output_music[playNr].repeat > _repetitions)
  {
    while(output_music[playNr].playlist_len > _trackNr)
    {
      _fileToPlay = output_music[playNr].file_nr[_index];
      _fileAddress = flash_table[_fileToPlay].address;
      _dataSize = flash_table[_fileToPlay].file_size;

      NAND_ReadFromFlash(&_fileAddress, WAV_HEADER_SIZE, file_data);

      wav_err = WAV_Open(&wav_file, file_data, &_fileAddress, _dataSize);

      if((wav_file.channel != 1) || (wav_err != WAV_NO_ERR))
      {
        //Bad wave file or,
        // Mono has 1 channel, stereo has 2 channels.
        // Theoretically there can be more than 2 channels, but we only play mono.
        ERROR_WAVEFile();
        LED_BusyOff();
        PIN_BusyOff();
        /* Disable audio amp */
        PIN_ShutdownReset();
        return;
      }

      _dataSize = wav_file.data_cksize;
      _fileAddress = wav_file.data_address;

      g_systemStatus.flag_isPlaying = 1;
      R_TPU0_SetFrequency(wav_file.sample_rate);

      if(_dataSize < sizeof(file_data))
      {
        _sizeToRead = _dataSize;
      }
      else
      {
        _sizeToRead = sizeof(file_data);
      }

      // Fill the buffer before enabling DMA to avoid blank interval.
      NAND_ReadFromFlash(&_fileAddress, _sizeToRead, file_data);
      g_decode_putp = 0;
      wav_put(file_data, _sizeToRead);
      _dataSize -= _sizeToRead;

      ERROR_ClearErrors();
      R_TPU0_Start();
      while(_dataSize > 0)
      {
        if(_dataSize >= sizeof(file_data))
        {
          _sizeToRead = sizeof(file_data);
        }
        else
        {
          _sizeToRead = _dataSize;
        }

        NAND_ReadFromFlash(&_fileAddress, _sizeToRead, file_data);

        wav_put(file_data, _sizeToRead);
        _dataSize -= _sizeToRead;

        if(!g_systemStatus.flag_isPlaying)
        {
          R_TPU0_Stop();
          R_DMAC1_SetAddresses((void*)&ringbuf, (void*)&DA.DADR1);  // Reset DMA address
          emptyPlayBuffer();
          LED_BusyOff();
          PIN_BusyOff();
          /* Disable audio amp */
          PIN_ShutdownReset();
          return;
        }
      }

      /* Wait until all data is sent to output (speakers) */
      uint32_t end_addr = (uint32_t)(ringbuf + g_decode_putp);
      do
      {
        R_WDT_Restart();
      }
      while((uint32_t)DMAC1.DMSAR != end_addr);

      R_TPU0_Stop();
      R_DMAC1_SetAddresses((void*)&ringbuf, (void*)&DA.DADR1);  // Reset DMA address
      emptyPlayBuffer();
      g_systemStatus.flag_isPlaying = 0;

      _trackNr++;
      _index++;
    }

    _trackNr = 0;
    _index = 0;
    _repetitions++;
  }

  LED_BusyOff();
  PIN_BusyOff();
  /* Disable audio amp */
  PIN_ShutdownReset();
}

static uint8_t I2C_Receive(sci_iic_info_t *i2c_info, uint8_t dev_add, uint8_t reg_add)
{
  volatile sci_iic_return_t ret;
  uint8_t _rx;

  i2c_info->cnt1st = 1;
  i2c_info->cnt2nd = 1;
  i2c_info->dev_sts = SCI_IIC_NO_INIT;
  i2c_info->p_data1st = &reg_add;
  i2c_info->p_data2nd = &_rx;
  i2c_info->p_slv_adr = &dev_add;

  ret = R_SCI_IIC_MasterReceive(i2c_info);
  if(SCI_IIC_SUCCESS == ret)
  {
    while(SCI_IIC_FINISH != i2c_info->dev_sts);
  }

  return _rx;
}

static void I2C_Send(sci_iic_info_t *i2c_info, uint8_t dev_add, uint8_t reg_add, uint8_t value)
{
  volatile sci_iic_return_t ret;

  i2c_info->cnt1st = 1;
  i2c_info->cnt2nd = 1;
  i2c_info->dev_sts = SCI_IIC_NO_INIT;
  i2c_info->p_data1st = &reg_add;
  i2c_info->p_data2nd = &value;
  i2c_info->p_slv_adr = &dev_add;

  ret = R_SCI_IIC_MasterSend(i2c_info);
  if(SCI_IIC_SUCCESS == ret)
  {
    while(SCI_IIC_FINISH != i2c_info->dev_sts);
  }

}
static void I2C_Init()
{
  /* GPIO Mux Reset pin */
  PIN_RstReset();
  R_BSP_SoftwareDelay(5, BSP_DELAY_MILLISECS);
  PIN_RstSet();

  iic_info.callbackfunc = &callBack_read;
  iic_info.ch_no = 11;
  iic_info.cnt1st = 1;
  iic_info.cnt2nd = 1;
  iic_info.dev_sts = SCI_IIC_NO_INIT;

  R_SCI_IIC_Open(&iic_info);

  /* Potentiometer init - do not write to EEPROM */
  I2C_Send(&iic_info, I2C_POTENT_ADDR, 2, 0x80);

  /* GPIO Mux Init */
  // IOCON
  I2C_Send(&iic_info, I2C_GPIO_ADDR, 0x0A, 0xC2);  // INT is active HIGH

  // IODIRA
  I2C_Send(&iic_info, I2C_GPIO_ADDR, 0x00, 0xFF);
  // IOPOLA
  I2C_Send(&iic_info, I2C_GPIO_ADDR, 0x01, 0);
  // GPINTENA
  I2C_Send(&iic_info, I2C_GPIO_ADDR, 0x02, 0xFF);
  // DEFVALA
  I2C_Send(&iic_info, I2C_GPIO_ADDR, 0x03, 0xFF);
  // INTCONA
  I2C_Send(&iic_info, I2C_GPIO_ADDR, 0x04, 0xFF);
  // GPPUA
  I2C_Send(&iic_info, I2C_GPIO_ADDR, 0x06, 0xFF);

  // IODIRB
  I2C_Send(&iic_info, I2C_GPIO_ADDR, 0x10, 0xFF);
  // IOPOLB
  I2C_Send(&iic_info, I2C_GPIO_ADDR, 0x11, 0);
  // GPINTENB
  I2C_Send(&iic_info, I2C_GPIO_ADDR, 0x12, 0xFF);
  // DEFVALB
  I2C_Send(&iic_info, I2C_GPIO_ADDR, 0x13, 0xFF);
  // INTCONB
  I2C_Send(&iic_info, I2C_GPIO_ADDR, 0x14, 0xFF);
  // GPPUB
  I2C_Send(&iic_info, I2C_GPIO_ADDR, 0x16, 0xFF);

  // Clear interrupts
  I2C_Receive(&iic_info, I2C_GPIO_ADDR, 0x09);
  I2C_Receive(&iic_info, I2C_GPIO_ADDR, 0x19);
}

static int getDataFromFlash()
{
  uint8_t is_data_in_flash;
  uint32_t flash_address = 0;

  /* Check if there is any data in flash. */
  is_data_in_flash = NAND_CheckDataInFlash(&flash_address);

  /* If data in flash, prepare lookout tables. */
  if(is_data_in_flash)
  {
    NAND_Reset();
    flash_address = (flash_address & 0xFFFF0000) + NAND_PAGE_SIZE;
    NAND_ReadFromFlash(&flash_address, sizeof(flash_table), (uint8_t*)&flash_table[0]);
    flash_address = (flash_address & 0xFFFF0000) + 2 * NAND_PAGE_SIZE;
    NAND_ReadFromFlash(&flash_address, sizeof(output_music), (uint8_t*)&output_music[0]);

  }
  else
  {
    return 0;
  }

  return 1;
}

void callBack_read()
{
  volatile sci_iic_return_t ret;
  sci_iic_mcu_status_t iic_status;
  sci_iic_info_t iic_info_ch;
  iic_info_ch.ch_no = 11;
  ret = R_SCI_IIC_GetStatus(&iic_info_ch, &iic_status);
  if(SCI_IIC_SUCCESS != ret)
  {
    /* Call error processing for the R_SCI_IIC_GetStatus()function*/
  }
}

static void sys_init()
{
  // SPI CS Pin
  PORTD.PDR.BIT.B4 = 1;  // Set pin as output
  NAND_CS_HIGH;

  // CPU init (cloks, RAM, etc.) and peripheral init is done in
  // resetpgr.c in PowerON_Reset_PC function.

  playMode = emptyPlay;
  R_DAC1_Start();
  R_DAC1_Set_ConversionValue(0x800);  // This is to avoid popping sound at the start
  I2C_Init();

  // Init USB Host Mass Storage Device controller
  ctrl.module = USB_IP0;
  ctrl.type = USB_HMSC;
  cfg.usb_speed = USB_FS;
  cfg.usb_mode = USB_HOST;
  R_USB_Open(&ctrl, &cfg);

  // Init SPI for NAND Flash
  memdrv_info.cnt = 0;
  memdrv_info.p_data = NULL;
  memdrv_info.io_mode = MEMDRV_MODE_SINGLE;

  R_MEMDRV_Open(0, &memdrv_info);
  NAND_Reset();
  NAND_CheckBlock();

  R_DMAC0_SetAddresses((void*)&S12AD.ADDR6, (void*)&volume);
  R_DMAC0_Start();
  R_ADC0_Start();
  R_DMAC1_SetAddresses((void*)&ringbuf, (void*)&DA.DADR1);
  R_DMAC1_Start();
  emptyPlayBuffer();
}

static uint8_t board_selection()
{
  if(PIN_GetDebugMode() == 1)
  {
    // Normal mode
    return PIN_BoardSelection();  // Solder jumpers MS1, MS2
  }
  else
  {
    // Debug mode
    return (((DIP_ReadState() ^ 0xFF) & 0xC0) >> 6);  // Pins 7, 8
  }
}

/*static uint8_t usb_copy_enable()
 {
 if(PIN_GetDebugMode() == 1)
 {
 //Normal mode
 return ((DIP_ReadState() & 0x40) >> 6);  //Pin 7
 }
 else
 {
 //Debug mode
 return ((DIP_ReadState() & 0x20) >> 5);  //Pin 6
 }
 }*/

void CNT_USB_LedCallback()
{
  LED_USBToggle();
}

void CNT_USB_CntCallback()
{
  usb_cnt++;
}

void CNT_IntervalDelay()
{
  static int del_cnt;

  // Because period is 100 ms, we have to multiply by 10 to get delay in seconds.
  if((del_cnt == (interval_time * 10)) || (g_systemStatus.flag_waitForInterval == 0))
  {
    R_CMT_Stop(cmt_channel_interval_delay);
    g_systemStatus.flag_waitForInterval = 0;
    del_cnt = 0;
  }

  del_cnt++;
}

/* Periodic ISR for polling status on GPIO MUX */
void ISR_periodicPolling()
{
  R_BSP_InterruptsEnable();
  uint8_t _volume;
  uint8_t gpio_rx[2];

  if(boardType == WAV_5F9IH)
  {
    // volume[0] is 16-bit variable, but contains 8-bit value. Potentiometer can accept only values from 0 to 127.
    _volume = (uint8_t)(volume[g_systemStatus.vol_ctrl_nr] >> 1);
  }
  else
  {
    _volume = 127;
  }

  // Activated when 0.
  if(0 == PIN_Get6dB() || 2 == g_binary_vol_reduction)
  {
    // -6dB is half
    _volume = _volume / 2;
  }
  else if(0 == PIN_Get14dB() || 5 == g_binary_vol_reduction)
  {
    // -14dB is fifth
    _volume = _volume / 5;
  }

  /* Send volume data to potentiometer */
  I2C_Send(&iic_info, I2C_POTENT_ADDR, 0, _volume);

  /* Read gpioa, gpiob from GPIO mux */
  gpio_rx[0] = I2C_Receive(&iic_info, I2C_GPIO_ADDR, 0x09);
  gpio_rx[1] = I2C_Receive(&iic_info, I2C_GPIO_ADDR, 0x19);

  g_systemStatus.flag_isIRQ = PIN_GetExtIRQ();

  playMode(gpio_rx);

  g_systemStatus.flag_semaphoreLock = 0;
}

/* main start */
void main(void)
{
  usb_status_t event;
  int isDataInFlash;
  nand_flash_status_t flash_status;
  uint8_t fifo_value;

  sys_init();

  /* Periodic timer for GPIO polling, period is  20 ms. */
  R_CMT_CreatePeriodic(50, &ISR_periodicPolling, &cmt_channel_i2c);

  /* Check if USB is inserted */
  // Create 100 ms counter for polling to check if USB is connected.
  R_CMT_CreatePeriodic(10, &CNT_USB_CntCallback, &cmt_channel_usb);
  while(usb_cnt < 10)
  {
    event = R_USB_GetEvent(&ctrl);  // Get event code
    R_WDT_Restart();

    switch(event)
    {
      case USB_STS_CONFIGURED:
        R_CMT_Stop(cmt_channel_i2c);  // Stop GPIO polling

        LED_USBOn();
        NAND_Reset();
        flash_status = NAND_CopyToFlash();
        if(flash_status != NAND_WRITE_OK)
        {
          isDataInFlash = 0;
        }
        else
        {
          // Create 500 ms counter for flashing USB LED.
          R_CMT_CreatePeriodic(2, &CNT_USB_LedCallback, &cmt_channel);
        }
        goto WHILE1;
        break;

      case USB_STS_DETACH:
        if(flash_status == NAND_WRITE_OK)
        {
          R_CMT_Stop(cmt_channel);
          LED_USBOff();
        }
        break;

      case USB_STS_NOT_SUPPORT:
        break;

      case USB_STS_NONE:
        break;

      default:
        break;
    }
  }
  R_CMT_Stop(cmt_channel_usb);

  isDataInFlash = getDataFromFlash();
  if(!isDataInFlash)
  {
    ERROR_FlashEmpty();
    R_CMT_Stop(cmt_channel_i2c);  // Stop GPIO polling
  }

  /* Determine board type */
  boardType = board_selection();

  /* Number of switches */
  if(boardType == WAV_5F1)
  {
    g_systemStatus.nr_of_switches = 4;
  }
  else if(boardType == WAV_5F9IH)
  {
    g_systemStatus.nr_of_switches = 12;
  }
  else
  {
    g_systemStatus.nr_of_switches = 8;
  }

  /* Mode select */
  mode_select = DIP_ReadState() & 0x07;  // Switches 1, 2, 3 are mode select
  switch(mode_select)
  {
    case 0:
      if(boardType == WAV_5F9IH)
      {
        playMode = lastInputInterruptPlay_5F9IH;
        R_CMT_Stop(cmt_channel_i2c);
        R_CMT_CreatePeriodic(400, &ISR_periodicPolling, &cmt_channel_i2c);  // 3,5 ms
      }
      else
      {
        playMode = normalPlay;
      }
      FIFO_Init(1);
      break;

    case 1:
      if(boardType == WAV_5F9IH)
      {
        playMode = binary255_5F9IH;
      }
      else
      {
        playMode = lastInputInterruptPlay;
      }
      FIFO_Init(1);
      break;

    case 2:
      if(boardType != WAV_5F9IH)
      {
        playMode = priorityPlay;
        FIFO_Init(1);
      }
      break;

    case 3:
      if(boardType != WAV_5F9IH)
      {
        playMode = inputPlay;
        FIFO_Init(1);
      }
      break;

    case 4:
      if(boardType == WAV_5A2)
      {
        playMode = binary127ch_negative;
        FIFO_Init(MAX_BIN_BUFF_SIZE);
      }
      break;

    case 5:
      if(boardType == WAV_5F2)
      {
        playMode = binary127ch_negative;
        FIFO_Init(MAX_BIN_BUFF_SIZE);
      }
      break;

    case 6:
      if(boardType == WAV_5A2)
      {
        playMode = binary250_negative;
      }
      if(boardType == WAV_5F2)
      {
        playMode = binary255_positive;
      }
      FIFO_Init(MAX_BIN_BUFF_SIZE);
      break;

    case 7:
      if(boardType == WAV_5A2)
      {
        playMode = binary250_positive;
        PIN_BusyReset();
      }
      if(boardType == WAV_5F2)
      {
        playMode = binary255_negative;
      }
      FIFO_Init(MAX_BIN_BUFF_SIZE);
      break;
  }

  /* Inverval select */
  uint8_t _interval_select = (DIP_ReadState() & 0x18) >> 3;  // Switches 4, 5 are interval select
  if((mode_select == 0) && (boardType != WAV_5F9IH))
  {
    switch(_interval_select)
    {
      /* Interval are 30, 60 and 120 s. */
      case 0:
        interval_time = 0;
        break;

      case 1:
        interval_time = 30;
        break;

      case 2:
        interval_time = 60;
        break;

      case 3:
        interval_time = 120;
        break;
    }
  }
  else
  {
    interval_time = 0;
  }

  /* Turn LED on after init is compleate and system is ready to run */
  if(isDataInFlash)
  {
    LED_PowOn();
  }

  /* Wait for interrupt from GPIO pins to start playing */
WHILE1: while(1)
  {
    R_WDT_Restart();
    /* Go to main part of program, only if data is available in flash. Otherwise loop and check if USB is attached. */
    if(isDataInFlash)
    {
      if(PIN_GetSW2() == 2)
      {
        // Position 1 (chime), continuous play of song nr. 1, volume adjustment on VR3
        g_systemStatus.vol_ctrl_nr = 0;
        playFromPlaylist(0, 1);
      }
      else if(PIN_GetSW2() == 1)
      {
        // Position 3 (voice), continuous play of song nr. 1, volume adjustment on VR4
        g_systemStatus.vol_ctrl_nr = 1;
        playFromPlaylist(0, 1);
      }
      else
      {
        /* Play song if anything is in queue */
        if(!g_systemStatus.flag_semaphoreLock)
        {
          while(FIFO_Get(&fifo_value, 1) != FIFO_EMPTY)
          {
            if(0xFF != fifo_value)
            {
              playFromPlaylist(fifo_value, 0);
            }

            /* Wait for interval time */
            if(interval_time && g_systemStatus.flag_isSongAvailable)
            {
              LED_BusyOn();
              PIN_BusyReset();
              g_systemStatus.flag_waitForInterval = 1;
              // 100 ms period
              R_CMT_CreatePeriodic(10, &CNT_IntervalDelay, &cmt_channel_interval_delay);
              while(g_systemStatus.flag_waitForInterval)
              {
                R_WDT_Restart();
              }
              LED_BusyOff();
              PIN_BusySet();
            }
            g_systemStatus.flag_semaphoreLock = 1;
          }
        }
      }
    }
  }
}

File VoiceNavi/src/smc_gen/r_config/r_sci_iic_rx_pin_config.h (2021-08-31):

/*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
 * Copyright (C) 2016 Renesas Electronics Corporation. All rights reserved.
 **********************************************************************************************************************/
/***********************************************************************************************************************
 * File Name    : r_sci_iic_rx_pin_config_reference.h
 * Description  : Pin configures the SCI IIC drivers
 **********************************************************************************************************************/
/***********************************************************************************************************************
 * History : DD.MM.YYYY Version  Description
 *         : 04.03.2016 1.90     First Release
 *         : 31.08.2017 2.20     Changed default value of macro definitions, below.
 *         :                      - R_SCI_IIC_CFG_SCI2_SSCL2_PORT
 *         :                      - R_SCI_IIC_CFG_SCI2_SSDA2_PORT, R_SCI_IIC_CFG_SCI2_SSDA2_BIT
 *         :                      - R_SCI_IIC_CFG_SCI3_SSCL3_PORT, R_SCI_IIC_CFG_SCI3_SSCL3_BIT
 *         :                      - R_SCI_IIC_CFG_SCI3_SSDA3_PORT, R_SCI_IIC_CFG_SCI3_SSDA3_BIT
 *         :                      - R_SCI_IIC_CFG_SCI5_SSCL5_PORT, R_SCI_IIC_CFG_SCI5_SSCL5_BIT
 *         :                      - R_SCI_IIC_CFG_SCI5_SSDA5_PORT, R_SCI_IIC_CFG_SCI5_SSDA5_BIT
 *         :                      - R_SCI_IIC_CFG_SCI6_SSCL6_BIT
 *         :                      - R_SCI_IIC_CFG_SCI6_SSDA6_BIT
 **********************************************************************************************************************/
/* Guards against multiple inclusion */
#ifndef SCI_IIC_PIN_CONFIG_H
    #define SCI_IIC_PIN_CONFIG_H
/***********************************************************************************************************************
 Configuration Options
 **********************************************************************************************************************/
/*------------------------------------------------------------------------------*/
/*   Set using port as sci iic port                                             */
/*------------------------------------------------------------------------------*/
/* Select the port group and pin used by setting
 "R_SCI_IIC_CFG_SCIx_SSCLx_PORT (select from port group 0 to K)"
 and "R_SCI_IIC_CFG_SCIx_SSCLx_BIT (select from pin number 0 to 7)"
 and "R_SCI_IIC_CFG_SCIx_SSDAx_PORT (select from port group 0 to K)"
 and "R_SCI_IIC_CFG_SCIx_SSDAx_BIT (select from pin number 0 to 7)",
 respectively. */

/* Select the ports (SSCL0 and SSDA0) to use in SCI0 */  
    #define R_SCI_IIC_CFG_SCI0_SSCL0_PORT   '2'        /* Port Number */  
    #define R_SCI_IIC_CFG_SCI0_SSCL0_BIT    '1'        /* Bit Number  */  

    #define R_SCI_IIC_CFG_SCI0_SSDA0_PORT   '2'        /* Port Number */  
    #define R_SCI_IIC_CFG_SCI0_SSDA0_BIT    '0'        /* Bit Number  */  

/* Select the ports (SSCL1 and SSDA1) to use in SCI1 */
    #define R_SCI_IIC_CFG_SCI1_SSCL1_PORT   '1'        /* Port Number */  
    #define R_SCI_IIC_CFG_SCI1_SSCL1_BIT    '5'        /* Bit Number  */  

    #define R_SCI_IIC_CFG_SCI1_SSDA1_PORT   '1'        /* Port Number */  
    #define R_SCI_IIC_CFG_SCI1_SSDA1_BIT    '6'        /* Bit Number  */  

/* Select the ports (SSCL2 and SSDA2) to use in SCI2 */
    #define R_SCI_IIC_CFG_SCI2_SSCL2_PORT   '1'        /* Port Number */  
    #define R_SCI_IIC_CFG_SCI2_SSCL2_BIT    '2'        /* Bit Number  */  

    #define R_SCI_IIC_CFG_SCI2_SSDA2_PORT   '1'        /* Port Number */  
    #define R_SCI_IIC_CFG_SCI2_SSDA2_BIT    '3'        /* Bit Number  */  

/* Select the ports (SSCL3 and SSDA3) to use in SCI3 */
    #define R_SCI_IIC_CFG_SCI3_SSCL3_PORT   '1'        /* Port Number */  
    #define R_SCI_IIC_CFG_SCI3_SSCL3_BIT    '6'        /* Bit Number  */  

    #define R_SCI_IIC_CFG_SCI3_SSDA3_PORT   '1'        /* Port Number */  
    #define R_SCI_IIC_CFG_SCI3_SSDA3_BIT    '7'        /* Bit Number  */  

/* Select the ports (SSCL4 and SSDA4) to use in SCI4 */
    #define R_SCI_IIC_CFG_SCI4_SSCL4_PORT   'B'        /* Port Number */  
    #define R_SCI_IIC_CFG_SCI4_SSCL4_BIT    '0'        /* Bit Number  */  

    #define R_SCI_IIC_CFG_SCI4_SSDA4_PORT   'B'        /* Port Number */  
    #define R_SCI_IIC_CFG_SCI4_SSDA4_BIT    '1'        /* Bit Number  */  

/* Select the ports (SSCL5 and SSDA5) to use in SCI5 */
    #define R_SCI_IIC_CFG_SCI5_SSCL5_PORT   'B'        /* Port Number */  
    #define R_SCI_IIC_CFG_SCI5_SSCL5_BIT    '1'        /* Bit Number  */  

    #define R_SCI_IIC_CFG_SCI5_SSDA5_PORT   'B'        /* Port Number */  
    #define R_SCI_IIC_CFG_SCI5_SSDA5_BIT    '2'        /* Bit Number  */
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

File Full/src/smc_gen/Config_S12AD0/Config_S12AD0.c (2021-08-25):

/*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
* Copyright (C) 2019 Renesas Electronics Corporation. All rights reserved.
***********************************************************************************************************************/

/***********************************************************************************************************************
* File Name    : Config_S12AD0.c
* Version      : 2.2.1
* Device(s)    : R5F5651EHxFP
* Description  : This file implements device driver for Config_S12AD0.
* Creation Date: 2021-08-25
***********************************************************************************************************************/

/***********************************************************************************************************************
Pragma directive
***********************************************************************************************************************/
/* Start user code for pragma. Do not edit comment generated here */
/* End user code. Do not edit comment generated here */

/***********************************************************************************************************************
Includes
***********************************************************************************************************************/
#include "r_cg_macrodriver.h"
#include "Config_S12AD0.h"
/* Start user code for include. Do not edit comment generated here */
/* End user code. Do not edit comment generated here */
#include "r_cg_userdefine.h"

/***********************************************************************************************************************
Global variables and functions
***********************************************************************************************************************/
/* Start user code for global. Do not edit comment generated here */
/* End user code. Do not edit comment generated here */

/***********************************************************************************************************************
* Function Name: R_Config_S12AD0_Create
* Description  : This function initializes the S12AD0 channel
* Arguments    : None
* Return Value : None
***********************************************************************************************************************/

void R_Config_S12AD0_Create(void)
{
    /* Cancel S12AD0 module stop state */
    MSTP(S12AD) = 0U;

    /* Disable and clear interrupt flags of S12AD0 module */
    S12AD.ADCSR.BIT.ADIE = 0U;
    S12AD.ADCMPCR.BIT.CMPAIE = 0U;
    S12AD.ADCMPCR.BIT.CMPBIE = 0U;
    IEN(PERIB, INTB186) = 0U;

    /* Set S12AD0 control registers */
    S12AD.ADCSR.WORD = _0000_AD_DBLTRIGGER_DISABLE | _0000_AD_SYNCASYNCTRG_DISABLE | _0000_AD_SINGLE_SCAN_MODE;
    S12AD.ADDISCR.BYTE = _00_AD_DISCONECT_UNUSED;

    /* Set channels and sampling time */
    S12AD.ADSSTR6 = _0B_AD0_SAMPLING_STATE_6;
    S12AD.ADSSTR7 = _0B_AD0_SAMPLING_STATE_7;
    S12AD.ADANSA0.WORD = _0040_AD_ANx06_USED | _0080_AD_ANx07_USED;
    S12AD.ADCER.WORD = _0000_AD_RESOLUTION_12BIT | _0000_AD_AUTO_CLEARING_DISABLE | _0000_AD_SELFTDIAGST_DISABLE | 
                       _0000_AD_RIGHT_ALIGNMENT;
    S12AD.ADCSR.WORD |= _1000_AD_SCAN_END_INTERRUPT_ENABLE;
    S12AD.ADADC.BYTE = _03_AD_4_TIME_CONVERSION | _80_AD_AVERAGE_MODE;

    /* Set compare control register */
    S12AD.ADCMPCR.WORD = _0000_AD_WINDOWB_DISABLE | _0000_AD_WINDOWA_DISABLE | _0000_AD_WINDOWFUNCTION_DISABLE;

    /* Set interrupt and priority level */
    ICU.SLIBR186.BYTE = 0x40U;
    IPR(PERIB, INTB186) = _01_AD_PRIORITY_LEVEL1;

    /* Set AN006 pin */
    PORT4.PMR.BYTE &= 0xBFU;
    PORT4.PDR.BYTE &= 0xBFU;
    MPC.P46PFS.BYTE = 0x80U;

    /* Set AN007 pin */
    PORT4.PMR.BYTE &= 0x7FU;
    PORT4.PDR.BYTE &= 0x7FU;
    MPC.P47PFS.BYTE = 0x80U;

    R_Config_S12AD0_Create_UserInit();
}

/***********************************************************************************************************************
* Function Name: R_Config_S12AD0_Start
* Description  : This function starts the AD0 converter
* Arguments    : None
* Return Value : None
***********************************************************************************************************************/

void R_Config_S12AD0_Start(void)
{
    IR(PERIB, INTB186) = 0U;
    IEN(PERIB, INTB186) = 1U;
    S12AD.ADCSR.BIT.ADST = 1U;
}

/***********************************************************************************************************************
* Function Name: R_Config_S12AD0_Stop
* Description  : This function stops the AD0 converter
* Arguments    : None
* Return Value : None
***********************************************************************************************************************/

void R_Config_S12AD0_Stop(void)
{
    S12AD.ADCSR.BIT.ADST = 0U;
    IR(PERIB, INTB186) = 0U;
    IEN(PERIB, INTB186) = 0U;
}
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

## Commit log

2021-07-02 Uploaded e2 studio project to repository.
    [r_bsp_config_readme.txt]
2021-07-09 Added full project.
    [r_bsp_config_readme.txt]
2021-07-15 Bug fixes for audio play. Now it plays when switch is pressed.
    [Pin.c]
2021-07-16 Prepared "Demo" for SPI NAND Flash testing.
2021-07-29 Writing to NAND flash from USB device. Reading data from flash and playing it.
2021-08-05 GPIO mux over I2C.
2021-08-12 Added play modes for 5F1 board. Reverted NAND FIFO buffer.
    [Pin.c]
2021-08-19 Added play modes for 5F1 board - bit mode 128.
2021-08-23 Added documentation for 5A2 board.
2021-08-23 Added GPIO init. Added ADC converter. Some changes to flash. Migration to RX651.
2021-08-25 Issue #2434 - flash write change. Just for demo - development of other modules.
    [Config_S12AD0.c]
2021-08-25 Issue #2432, #2430 - I2C sending and receiving is now periodical with 22 Hz (45 ms).
    [Config_S12AD0.c, PORT_config.c]
2021-08-26 Issue #2432 - implemented DMA for reading analog potentiometer value. Writing to digital potentiometer.
    [ADC0.c, Config_S12AD0.c]
2021-08-27 Fix #2432 - real time volume control.
    [ADC0.c]
2021-08-27 Fix #2430 - button debounce fix. Implemented 45 ms sampling.
    [play_modes.c]
2021-08-31 Fix #1 - applied DMA for playing sound. Can play 8-bit and 16-bit, only mono sound.
    [ADC0.c]
2021-09-01 Added checklist.
    [IHE8001チェック5A2.xlsx]
2021-09-01 Issue #2 - Normal play mode implementation.
    [play_modes.c]
2021-09-02 Issue #2 - Normal play mode; code refactoring.
    [play_modes.c]
2021-09-02 Issue #2 - Last input play mode implementation.
    [IHE8001チェック5A2.xlsx]
2021-09-02 Issue #2 - Priority play mode implementation.
    [IHE8001チェック5A2.xlsx]
2021-09-02 Issue #2 - Input play mode implementation.
    [IHE8001チェック5A2.xlsx]
2021-09-03 Issue #2 - All binary play modes implementation.
    [IHE8001チェック5A2.xlsx]
2021-09-06 Moved to VoiceNavi folder.
    [r_bsp_config_readme.txt]
2021-09-06 Removed Demo project.
    [r_bsp_config_readme.txt]
2021-09-06 Issue #4 - implemented saving volume reduction to NAND Flash.
    [VoiceNaviMain.c, play_modes.c]
2021-09-07 Fix #5 - busy signal shows on output. Reduced sampling time for GPIO pins to 20 ms (50 Hz).
    [PORT_config_user.c, VoiceNaviMain.c]
2021-09-07 Issue #4 - volume reduction is saved to NAND flash for binary play mode.
    [VoiceNaviMain.c, play_modes.c]
2021-09-08 Issue #6 - reverted. Popping sound is HW problem.
    [VoiceNaviMain.c]
2021-09-09 Flash - always wire on new page. Don't write on same page twice.
    [IHE8001チェック5A2.xlsx]
2021-09-09 Fixed bug in bit order.
    [play_modes.c]
2021-09-09 Added comment.
    [IHE8001チェック5A2.xlsx]
2021-09-13 Readme edit, commented out LED_USBToggle.
2021-09-13 Enabled USB lED, to see when copying started and ended.
2021-09-21 Fix #9 - Inverted read inputs for DIP switch.
    [PORT_config_user.c]
2021-09-22 Fix #8 - moved mode reading to interrupt routine from main. Improved handling for binary play modes.
    [PORT_config_user.c, VoiceNaviMain.c, play_modes.c]
2021-09-22 Restart from STOP with binary play mode - fix.
    [VoiceNaviMain.c]
2021-09-27 Issue #16 - fixed to one shot input.
    [play_modes.c]
2021-09-27 Issue #15 - during interval wain, don't put songs into play queue; fixed.
    [VoiceNaviMain.c]
2021-09-27 Issue #14 - during interval wait time, LED and BUSY signals are set.
    [VoiceNaviMain.c]
2021-09-27 Issue #11 - STOP signal stops play also during repeated or combined songs.
    [VoiceNaviMain.c]
2021-09-27 Issue #13 - reversed positive and negative binary play mode.
    [VoiceNaviMain.c]
2021-09-27 Issue #16 - same switch can interrupt same song.
    [play_modes.c]
2021-09-27 Issue #13 - fixed positive and negative logic for binary modes.
    [VoiceNaviMain.c, play_modes.c]
2021-09-27 Issue #16 - priority play interrupts same level of priority of higher.
    [play_modes.c]
2021-09-28 Issue #14 - if undefined song is played, interval timer doesn't start.
    [VoiceNaviMain.c]
2021-09-28 Code refactoring 2. Fixed deadlock in inputPlay mode.
    [VoiceNaviMain.c, play_modes.c]
2021-09-28 Issue #16 - priority mode has also level play, not only one shot.
    [play_modes.c]
2021-09-28 Added support for 5F1 and 5F2 board. Issue #13 - switched positive and negative logic for binary mode.
    [VoiceNaviMain.c, play_modes.c]
2021-09-29 Fix #7 - USB LED blinks after copy from USB to flash is done. Added support for VR3 and VR4 volume control.
    [PORT_config_user.c, VoiceNaviMain.c]
2021-09-30 Updated Readme. Added test files and specification files.
    [IHE8001 MODEチェック4機種.xlsx, IHE8001チェック5A2.xlsx]
2021-10-05 Hardware revision 1.
    [Amp.SchDoc, Audio Prj.PrjPcb, Audio Prj.SCHLIB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]
2021-10-07 Updated check list.
    [IHE8001 MODEチェック4機種.xlsx]
2021-10-11 Updated check sheet.
    [IHE8001 MODEチェック4機種.xlsx]
2021-10-11 Issue #20 - 0xFA is 1 in negative binary 250 mode
    [play_modes.c]
2021-10-11 Issue #17 - stop GPIO polling while copying to NAND flash.
    [VoiceNaviMain.c]
2021-10-12 Issue #13 - reverted positive and negative binary modes.
    [play_modes.c]
2021-10-20 Issue #13 - binary mode stops immediately if 0x00 or 0xFF is received.
    [play_modes.c]
2021-10-22 Updated checklist. Removed wrong error commit.
    [IHE8001 MODEチェック4機種.xlsx, IHE8001 MODEチェック4機種1022.xlsx]
2021-10-26 Fix #22 - Changed play mode. On channel 0, play mode for 5F9 is last input interrupt play.
    [ADC0.c]
2021-11-12 Fix #27 - to enter into debug mode, solder JP1. If left opened, normal operation mode is selected.
    [PORT_config_user.c, VoiceNaviMain.c]
2021-11-15 Ref #28 add file IHE8001 MODEチェック4機種チェック1115.xlsx
    [IHE8001 MODEチェック4機種チェック1115.xlsx]
2021-11-15 Updated checklist. Removed wrong error commit. Don't add new files! Save changes to current file and commit it!
    [IHE8001 MODEチェック4機種.xlsx, IHE8001 MODEチェック4機種チェック1115.xlsx]
2021-11-15 Revert "Updated checklist. Removed wrong error commit."
    This reverts commit 81bca6530918ca1b92192c37c72127dd9cf83017.
    [IHE8001 MODEチェック4機種.xlsx, IHE8001 MODEチェック4機種チェック1115.xlsx]
2022-02-08 Fix #29 - implemented IRQ instead of polling for 5F9 binary play mode.
    [PORT_config.c, VoiceNaviMain.c, play_modes.c]
2022-02-10 Switched MS1 and MS2 pins.
2022-02-10 Set I2C speed to 384 kHz (max for CPU).
2022-02-16 VR3 and VR4 volume controls are only available on 5F9IH board. Fixed wrong board detection.
    [PORT_config_user.c, VoiceNaviMain.c]
2022-02-24 Data from USB are copied on startup. No more live copy with DIP switch 7.
2022-03-01 Fix #31 - changed binary STOP signal. Added check for mono and stereo sound.
    [VoiceNaviMain.c, play_modes.c]
2022-04-01 Binary mode channel select, address, and stop command #32
    Error if stereo file is being played. Playmode code refactoring.
    [VoiceNaviMain.c, play_modes.c]
2022-04-01 bug: Data from USB are copied on startup
    If empty flash and USB inserted, error showing empty flash would appear before copying data from USB to flash. Fixed bug.
    [VoiceNaviMain.c]
2022-04-05 bug: 5F9 normal play mode not working #35
    Bug is now fixed, introduced in 45fcea581293f8e339a4f3677873bf2401642c7a.
    [VoiceNaviMain.c]
2022-04-05 bug: Binary modes play range #34
    Extended number of playable channels.
    [play_modes.c]
2022-04-05 bug: Negative Busy signal on 5A2 #33
    Added condition statement to change pin polarity if 5A2 board and positive 8-bit binary mode is selected.
    [VoiceNaviMain.c]
2022-04-08 bug: Skipping bad blocks not working #37
    Fixed address counting if bad sectors are skipped. Added flash overflow check.
    [VoiceNaviMain.c]
2022-04-08 enh: Change errors table #36
    Changed LED error states. Updated readme file with new table.
    [VoiceNaviMain.c]
2022-04-20 hw: New hardware revision.
    [Amp.SchDoc, Audio Prj.PrjPcb, Audio Prj.SCHLIB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]
2022-04-22 bug: Popping sound #39
    Fixed bug introduced with commit: ac1170cda641362c732f92e4deb73e2e657df66c
    [VoiceNaviMain.c]
2022-04-27 bug: Output sound is cut at the beginning #40
    Fixed cut sound at start. Reduced delay from start signal to actual playback.
    [VoiceNaviMain.c]
2022-05-06 bug: Output sound is cut at the beginning #40
    8-bit audio was stuck in first loop when filling play buffer. Fixed.
    [VoiceNaviMain.c]
2022-05-06 bug: Flash management for playlist table.
    Configured flash management for playlist table. If corrupted blocks are in beginning of flash, those blocks are skipped and data is written to next available block.
    [VoiceNaviMain.c]
2022-05-17 bug: Interrupt play was stuck in infinite loop.
    If forcefully stopped (interrupted), DMA buffer address wasn't reset. Added reset address.
    [VoiceNaviMain.c]
2022-05-20 enh: Watchdog implementation #43
    Implemented WDT. It starts automatically on power on. Period is about 522 ms.
2022-05-20 bug: Weird sound output on channels 9 to 12 #44
    Bug fixed. uint16_t value was going into uint8_t variable.
    [play_modes.c]
2022-06-12 bug: On interval delay watchdog timer triggers #45
    Because program was holding in while loop, watchdog timer reset the program. Added WDT reset into holding loop.
    [VoiceNaviMain.c]
2022-06-13 bug: Normal play mode channels should not alternate #46
    Reset previously pressed switch only if input is released. If input is pressed, remember previously pressed switch.
    [play_modes.c]
2022-06-13 bug: Input play mode doesn't cut the song #47
    Inserted detection if 2 signals are set at the same time. After double input, break the song playing and play the input that is still set.
    [play_modes.c]
2022-06-13 bug: Ignore 8-bit data on 7-bit play mode
    Instead of ignoring just 7th bit, ignore all channels that are bigger than 127 (7-bit).
    [play_modes.c]
2022-06-15 bug: One count is missing when playing a WAVE file #50
    When fixing issue #40, round buffer check was shortened by 1 count.
    To fix the current bug, round buffer check was restored and buffer size increased.
    When 8-bit song is played, only half of the buffer is used.
    When 16-bit song is played 1/4 of the buffer is used.
    [VoiceNaviMain.c]
2022-07-06 bug: Pressing STB while STOP is pressed results in BUSY LED blink #58
    Inside binary play modes, when checking if stop is pressed, return from function if pressed. Previously it didn't return.
    [play_modes.c]
2022-07-06 enh: Processing when an error occurs #52
    If any error is detected, MCU goes to infinite while loop. MCU can be reset (software reset) if STOP is pressed.
    [VoiceNaviMain.c, play_modes.c]
2022-07-08 bug: Switch debounce - chattering #54
    If to consecutive scans (20 ms) show pressed button, we assume that a button is pressed.
    [VoiceNaviMain.c, play_modes.c]
2022-07-11 bug: Only 460ms of audio data of 500ms is played #56
    DMA was stopped before all the data could be output. Introduced wait loop to wait for DMA to finish everything.
    Removed forgotten test code (LED_USBOff).
    Disabled I2C polling after data is copied from USB.
    [VoiceNaviMain.c, play_modes.c]
2022-07-12 bug: Issue with binary FIFO queue #57
    Changed binary play mode to have FIFO queue. Previous specs were to have normal queue while playing.
    [VoiceNaviMain.c, play_modes.c]
2022-07-12 bug: Does not play with 3ch simultaneously #55
    Fixed Normal Play mode. It now supports all switches being pressed simultaneously.
    [play_modes.c]
2022-07-13 enh: Custom fmt chunk #49
    Improved parsing of WAVE file header. It should only get the information we need, regardless of number of chunks, and ignore other chunks.
    Previously parsing was limited to fixed, 44 byte header. Improved parsing so it checks for the correct chunk and fetches only data that is needed.
    No more fixed "fmt " chunk size.
    [VoiceNaviMain.c]
2022-07-13 bug: Issue with binary FIFO queue #57
    Few bugs were left after changing to FIFO queue.
    [VoiceNaviMain.c, play_modes.c]
2022-07-19 bug: Binary 7 bit mode #59
    In binary 7-bit mode, ignore MSB. Look just at 7 LSBs - example 0x95 == 0x15.
    [play_modes.c]
2022-07-22 Revert "enh: Processing when an error occurs #52"
    This reverts commit e224e53f1f13ccd0e31e0ad02e26d572b203eecf.
    Resetting error only resets LEDs. It happens after new input signal is detected (any channel or stop signal).
    Implemented better wave file error detection. If file is partially corrupted, if by the time we reach end of file we don't get fmt and data chunk info, error flag is set.
    [VoiceNaviMain.c, play_modes.c]
2022-07-25 bug: Error status not showing on bad wave file #62
    When creating CMT timer, the same channel was auto chosen for I2C polling and for errors. Errors now have fixed CMT channel - 3.
2022-07-26 bug: ERR check #63
    Improved checking if USB flash drive has correct file system or not. Also, some error messages were wrong.
    [VoiceNaviMain.c]
2022-07-29 bug: Short files - busy signal always on #71
    If file size is shorter than buffer size, read only file size.
    [VoiceNaviMain.c]
2022-07-29 bug: Stereo file error - busy signal stays on #73
    Only LED turned off when stereo file error was called. Forgot to also turn off busy pin. Fixed.
    [VoiceNaviMain.c]
2022-08-02 bug: FIFO queue 5 slots #74
    When FIFO is full, it has to wait 5 slots until we can put data in again.
    [VoiceNaviMain.c, play_modes.c]
2022-08-03 bug: Normal play mode - scanning next switch #75
    Example: if CH1 was played and stopped, next time SW1 and SW2 are pressed simultaneously, CH2 should start playing. Before the fix, CH1 started playing.
    [play_modes.c]
2022-08-05 bug: Debounce on individual channel #76
    Any switch must be pressed for 3 consecutive scans. If on first and last scan a the same switch is pressed, we assume that pulse is long enough (50 ms or more) and go into play mode.
    [VoiceNaviMain.c, play_modes.c]
2022-08-05 bug: Debounce on individual channel #76
    Always check switch status 3 times, when first input signal comes.
    [VoiceNaviMain.c, play_modes.c]
2022-08-05 bug: Input play not working as expected #77
    Play mode adjusted according to specifications. Also found a bug when song play is interrupted - busy signal didn't go to off state.
    [VoiceNaviMain.c, play_modes.c]
2022-08-12 bug: Stereo file error - busy signal stays on #73
    PIN_ShutdownReset() wasn't called if stereo or wave file error occurred. Fixed.
    [VoiceNaviMain.c]
2022-08-12 bug: FIFO queue 5 slots #74
    FIFO queue status did not reset if STOP signal was pressed. Fixed.
2022-08-12 bug: Normal play mode - scanning next switch #75
    During level play, if switch(es) are pressed, and STOP in introduced, start playing last played channel after stop is released.
    [play_modes.c]
2022-08-17 bug: last input interrupt play multi input fix
    Multi input wasn't working. Only 1 or 2 switches were working. Now, you can press all the switches and only the last pressed channel will play.
    [play_modes.c]
2022-08-23 bug: Problems with debounce #79
    Changed polling frequency 60 -> 65 Hz. Changed TUP0 interrupt priority from 15 to 13. Minor bug fixes in lastInputInterruptPlay().
    [VoiceNaviMain.c, play_modes.c]
2022-08-23 bug: Problems with debounce #79
    Reverted changes from commits: fb99b7e43ed17c6dd3ab5cf8e45db1de0d2adf7f and 75be721b1dd858583bdb0bc5dac36ead643cbca6. New mechanism for detecting 2 consecutive pulses on all channels.
    [VoiceNaviMain.c, play_modes.c]
2022-08-29 bug: No debounce in binary play mode #80
    Implemented debounce on GPIOB (GPIO mux). In binary mode, only STOP and STB pins are effected by debounce. SW1 to SW8 are not.
    [play_modes.c]
2022-08-29 bug: No debounce in binary play mode #80
    Different debounce time for 5F9 board. No more interrupt, just polling.
    [Pin.c, VoiceNaviMain.c]
2022-08-29 test: updated 50ms pulse test case.
2022-08-31 bug: double scan on all pins in binary mode
    Previously only GPIOB had debounce feature. Now both GPIOB and GPIOA have debounce feature.
    [play_modes.c]
2022-09-01 bug: 5F9 normal play mode not working #35
    Do not interrupt the same channel. Interrupt only different channels.
    [VoiceNaviMain.c, play_modes.c]
2022-09-01 enh: faster polling time for 5F9 board.
    Polling time changed from 3,5 ms to 2,5 ms.
2022-09-02 enh: faster polling time for 5F9 board.
    Forgot to remove LED_USBToggle().
2022-09-07 bug: USB_LED #81
    After data copy from USB to flash is finished, goto while(1) loop regardless of NAND_WRITE status. If write was success, start led success pattern, otherwise error pattern.
    [VoiceNaviMain.c]
2022-09-15 bug: 5F9 lastInputInterruptPlay_5F9IH mode #84
    Changed already_pressed_mask variable from uint8_t to uint16_t.
    [play_modes.c]
2022-09-15 bug: 5A2,5F1,5F2 inputPlay mode #83
    Reverted changes and implemented the correct stop condition.
    [play_modes.c]
2023-12-10 Added Modified hardware
    [Amp.SchDoc, Audio Prj.PrjPcb, Audio Prj.SCHLIB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]
